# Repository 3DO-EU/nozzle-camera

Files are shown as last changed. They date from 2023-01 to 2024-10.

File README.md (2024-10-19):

# 3DO NOZZLE CAMERA

**This repository is archived. Please visit the new project at [https://github.com/3DO-EU/Enclosure-Nozzle-Camera-V2](https://github.com/3DO-EU/Enclosure-Nozzle-Camera-V2)**

3DO Discord Server

After seeing a lot of cool nozzle camera videos with hacked-up endoscopes...
We decided to make a real "Nozzle Camera" for 3D printers.
We ended up making this.
- MIPI Camera with an external USB webcam encoder (to make the camera as small as possible)
- Fixed focus lens (AF lenses start to shake and lose focus when moving fast)
- Custom FEP+Silicone USB cable, as we couldn't find any high-temperature flexible USB cables on the market.
- Custom SK6812 WWCW LED, we wanted as much light as possible while keeping the SK6812 protocol; therefore, we ended up making our LEDs similar to RGBW but with only white diodes inside.

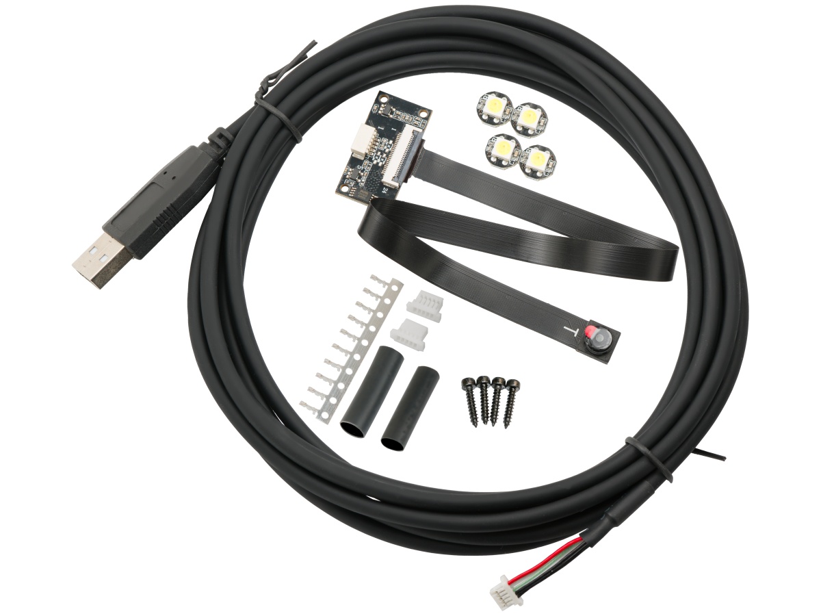
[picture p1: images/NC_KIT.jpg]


| | 4K (Sony IMX258) |
|---|---|
| Sensor Size | 1/3.06 |
| Mega-Pixel | 13MP |
| Frame Rate* | 30FPS@4K 60FPS@1080P* |
| Lens type* | Fixed Focus |
| FoV | 80Deg |
| FPC length | 25cm |
| Operating temperature** | -20°C TO 65°C |
| Storage temperature | -40°C TO 80°C |

_*These frame rates represent what the camera can achieve when directly connected, such as in OBS Studio or the Windows webcam app._

_When streaming through Crowsnest on a Raspberry Pi or a similar device, two factors limit your performance: GPU power and bandwidth._

_The new version of Crowsnest supports WebRTC/H.264 streaming, significantly reducing bandwidth requirements, making it less of a concern. However, when using the WebRTC streaming function, your GPU's encoding capabilities become the limiting factor (For Raspberry Pi 4, the GPU is limited to 1080p at 38 FPS and cannot encode 4K)._

_If you opt for the MJPEG stream in Crowsnest, no encoding is necessary, eliminating GPU limitations. However, this method requires considerably more bandwidth, so your FPS will be restricted by the available network bandwidth (using an Ethernet cable instead of Wi-Fi is recommended)._

## Video
3DO Nozzle Camera teaser (https://www.youtube.com/watch?v=BjG8rhLlGIU)

## Folders
- printers (mounts for different printers)
- hardware (CAD files to help design printer mounts)

## Pinout
PCB uses a 5P 1.0mm pitch connector.
| Pin No. | Function | Color |
|---|---|---|
| 1 | USB 5VDC | Red |
| 2 | Data - | White |
| 3 | Data + | Green |
| 4 | USB -VDC/GND| Black |
| 5 | GND/Shield  | Black (heat shrink)  |

Wire no. 5 is an optional shield/drain wire, though it will work without, we recommend installing it.

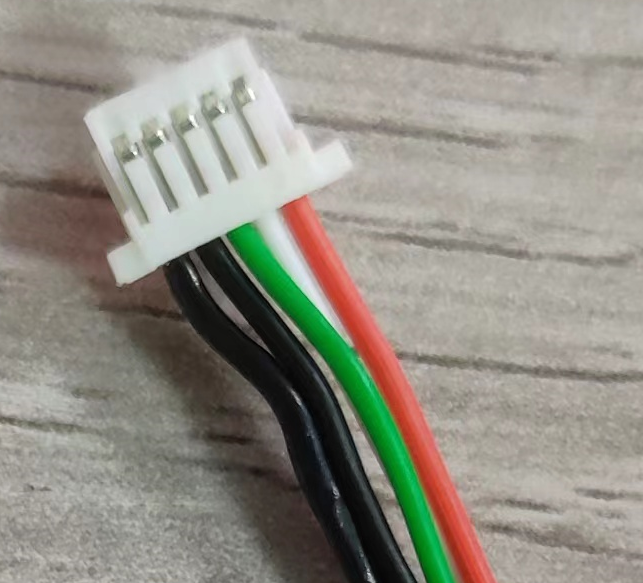
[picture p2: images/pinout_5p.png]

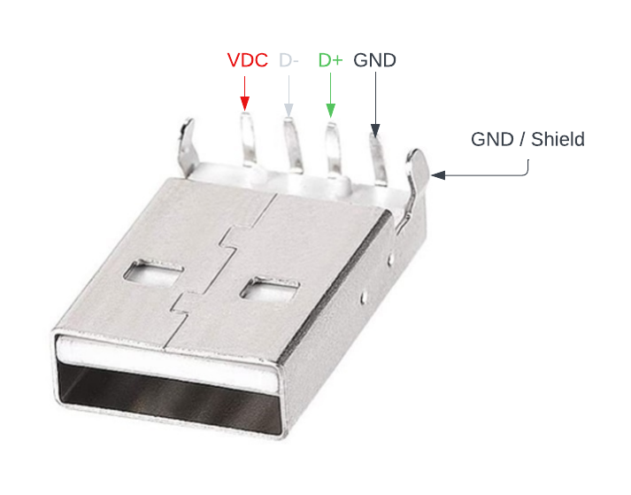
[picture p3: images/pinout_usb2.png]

</br>

## Software
The camera works as a standard UVC web camera and is, therefore, compatible with Linux, Windows, and Mac.
For streaming, we recommend using [mainsail](https://github.com/mainsail-crew/mainsail) + [crowsnest](https://github.com/mainsail-crew/crowsnest).

## FAQ
- Does it work in an enclosed printer?

Yes, though our camera is rated at 60°C, we have been running it for 48 hours in a 70°C industrial heat chamber without any issues.
- Why is FPC so long?

We decided on having 25cm between the camera and PCB for more flexibility in future mount designs.
- Can I bend/fold the FPC to make it shorter?

Yes, FPC is flexible and can be bent; if you want to fold it (180 degrees), we recommend doing this max one time in the same spot, or else you risk breaking the lanes inside FPC.

Example of folding FPC

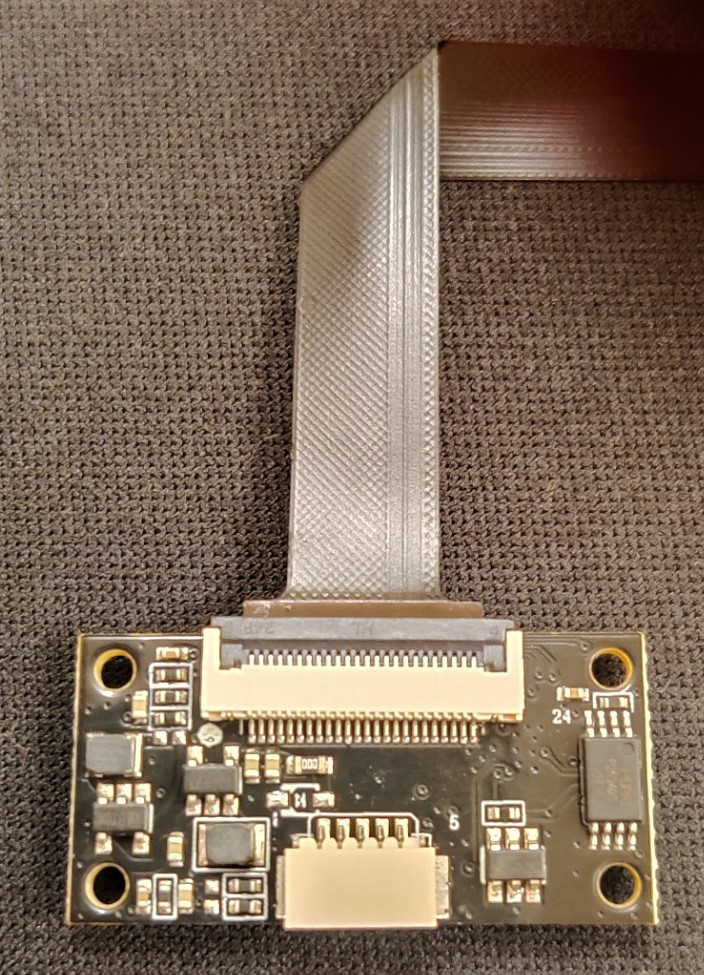
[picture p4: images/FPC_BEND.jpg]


## Contributors that made this project possible
CAD Design & Testing
- Olof Ogland (Known from Bondtech)
- Kenneth Munkholt (VZ Community)
- Dennis Jespersen (From RatRig Community)

Software Development & Testing
- Meteyou (Mainsail founder)
- KwadFan (Crowsnest founder)
- Rogerlz (Crowsnest Tester)

Beta Testers
- Mitsuma (From RatRig Community)
- Joao Barros (From RatRig Community)

## Where to buy
EU / UK



USA





<p xmlns:cc="http://creativecommons.org/ns#" >This work is licensed under <a href="https://creativecommons.org/licenses/by-nc-sa/4.0/?ref=chooser-v1" target="_blank" rel="license noopener noreferrer" style="display:inline-block;">CC BY-NC-SA 4.0</a></p>

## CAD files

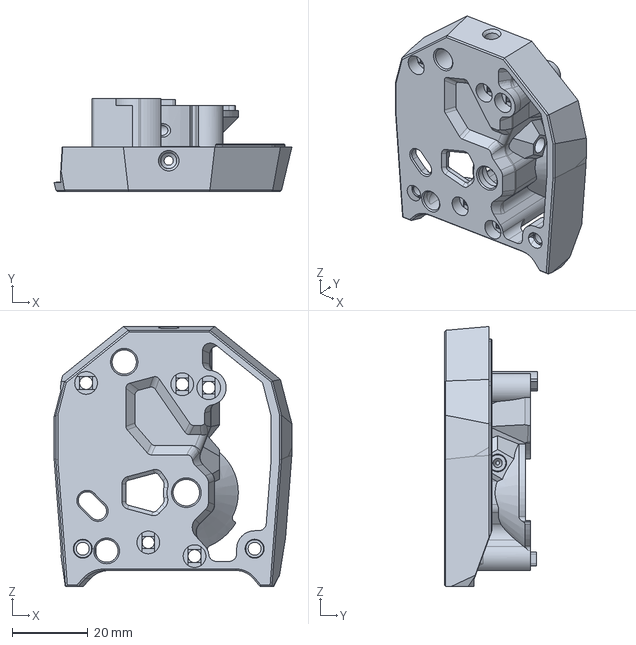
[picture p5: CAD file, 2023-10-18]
printers/Voron_Stealthburner/CAD/Misc/CW2 main body 3DO mod_updated.step
62.8 x 24.7 x 68.7 mm

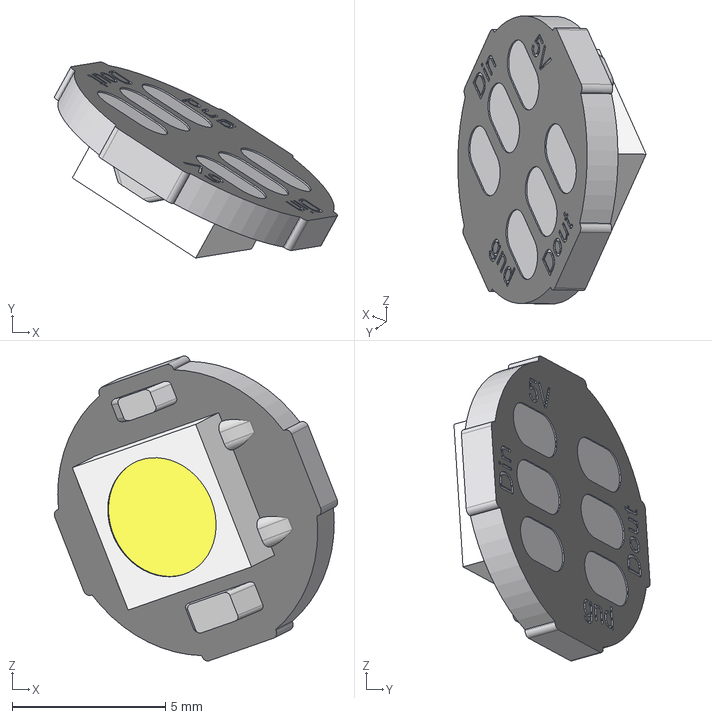
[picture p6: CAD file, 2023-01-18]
hardware/3NC_LED.stp
9.24 x 6.39 x 9.95 mm

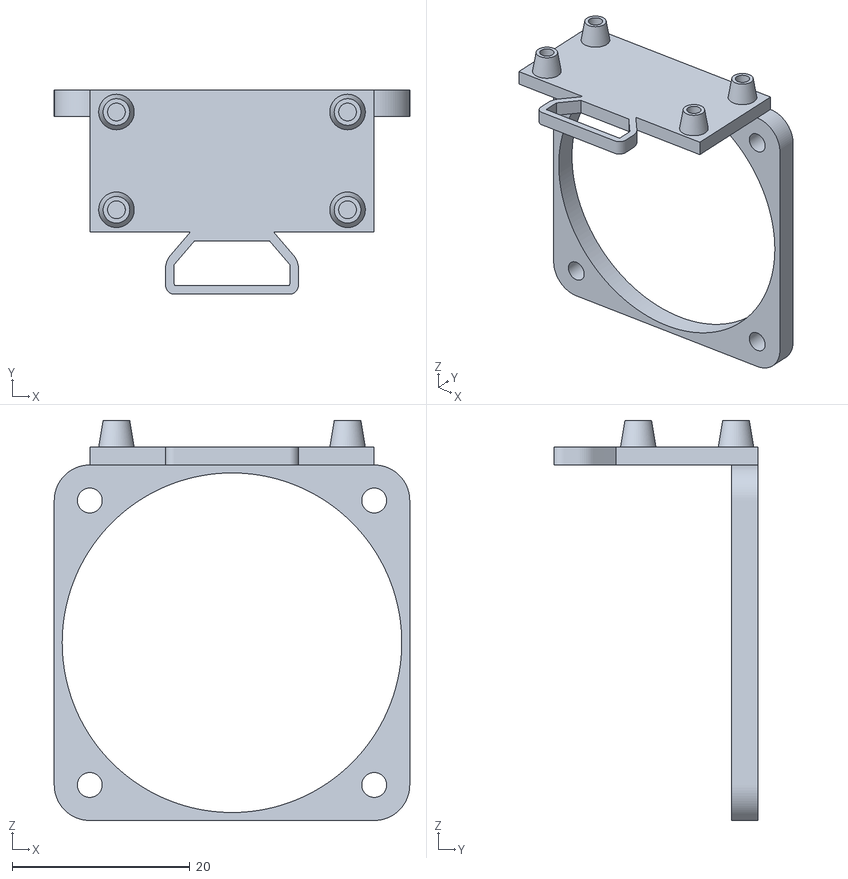
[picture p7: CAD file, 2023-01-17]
printers/EVA_2_4/Body1.stl
40.0 x 23.0 x 45.0

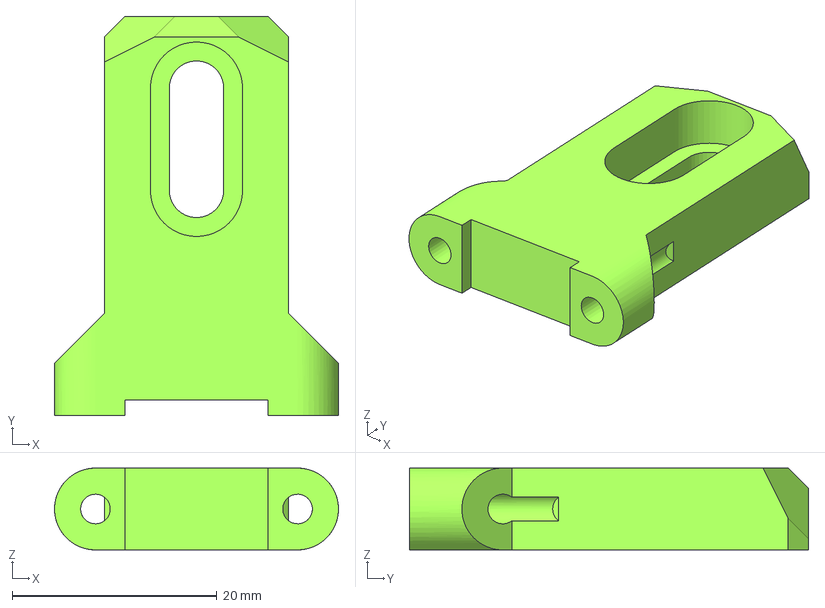
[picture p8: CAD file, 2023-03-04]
printers/EVA_3/Y end stop extended 15mm.3mf
27.7 x 39.0 x 8.00 mm

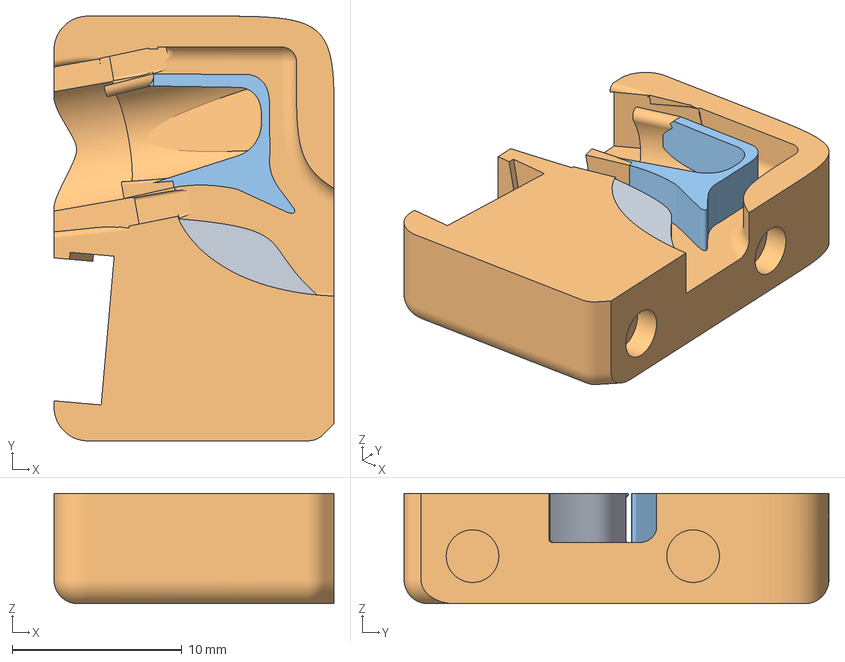
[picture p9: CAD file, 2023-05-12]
printers/Prusa I3 MK3/Nozzle-Cam 3DO 4K V13 LED Pearl A.3mf
16.5 x 25.0 x 6.50 mm
K_rper_15
Cambody
K_rper_16

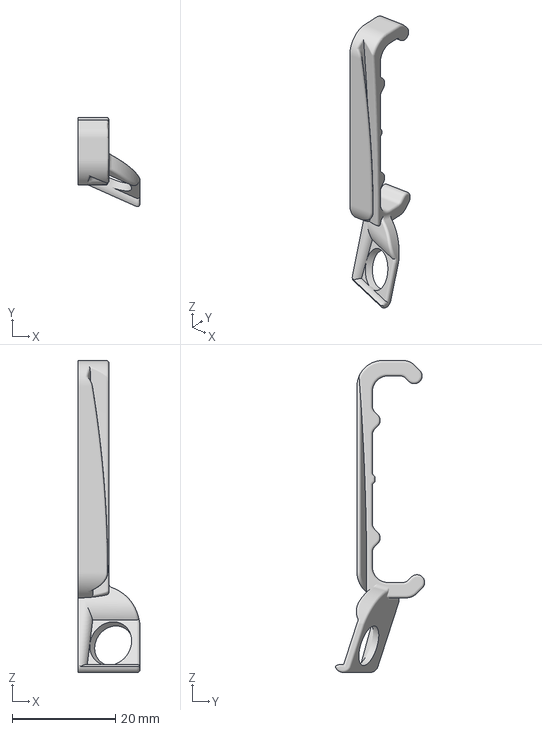
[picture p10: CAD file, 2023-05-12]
printers/Prusa Mini/3DO Nozzle Cam Fan Mount for Prusa Mini - 22 deg right and 16.5 deg down V7.3.3mf
12.0 x 17.3 x 60.4 mm

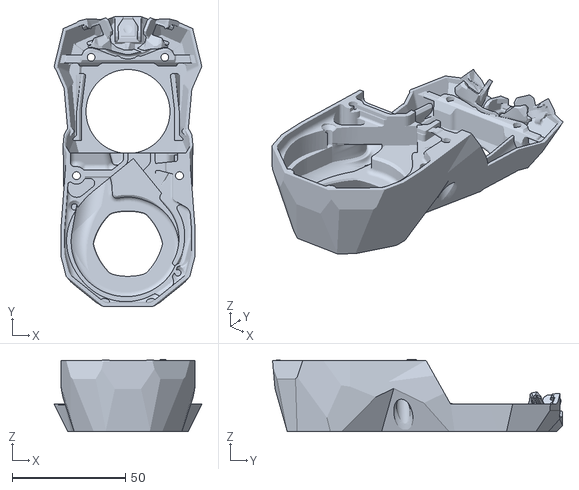
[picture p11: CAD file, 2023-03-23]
printers/Voron_Stealthburner/STLs/Standard/Cam_mount_SB_HEX.stl
65.1 x 127.8 x 31.8

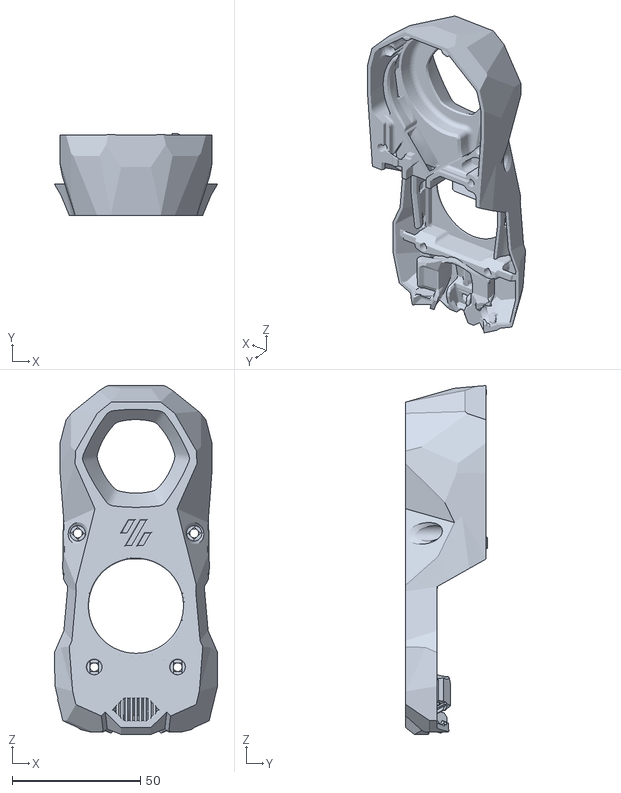
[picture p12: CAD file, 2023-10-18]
printers/Voron_Stealthburner/STLs/UHF/Cam_mount_SB-UHF_Grille_eyebrows.stl
63.6 x 31.8 x 136.1

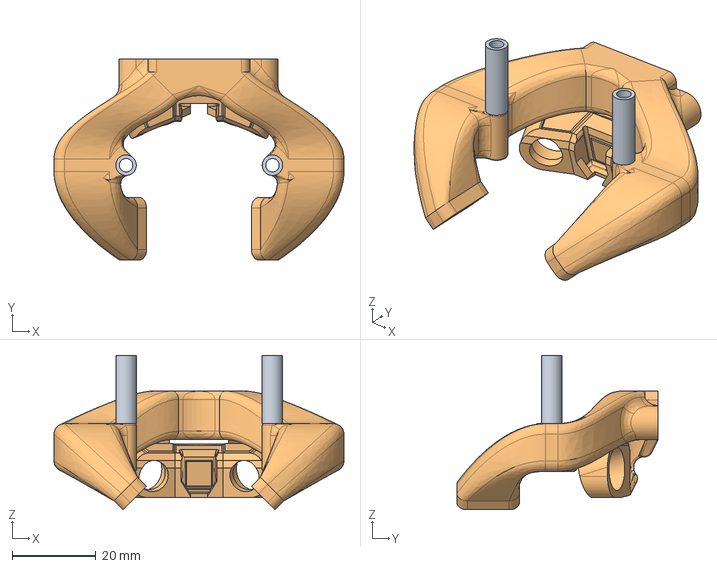
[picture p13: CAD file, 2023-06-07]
printers/VzBoT/Duct.step
69.3 x 48.2 x 36.9 mm

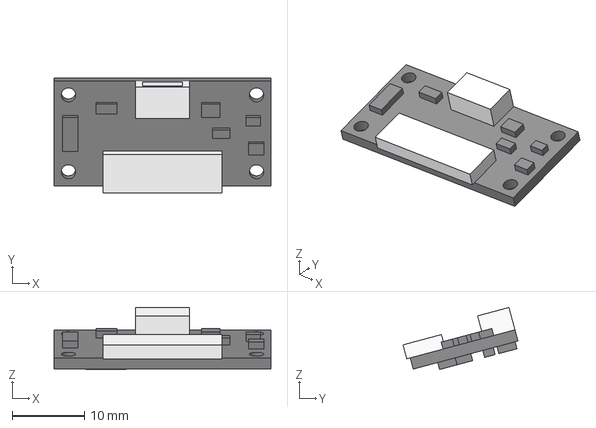
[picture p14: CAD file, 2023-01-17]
hardware/3NC_pcb.stp
30.0 x 15.9 x 8.58 mm

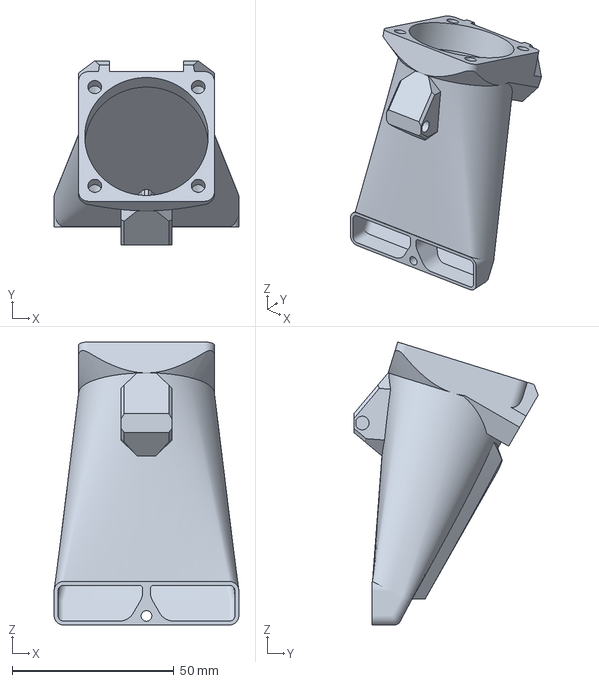
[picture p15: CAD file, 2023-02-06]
printers/EVA_3/3DO EVA 4028 fan inlet nozzle cam pcb mount V2.3mf
57.2 x 57.1 x 87.6 mm

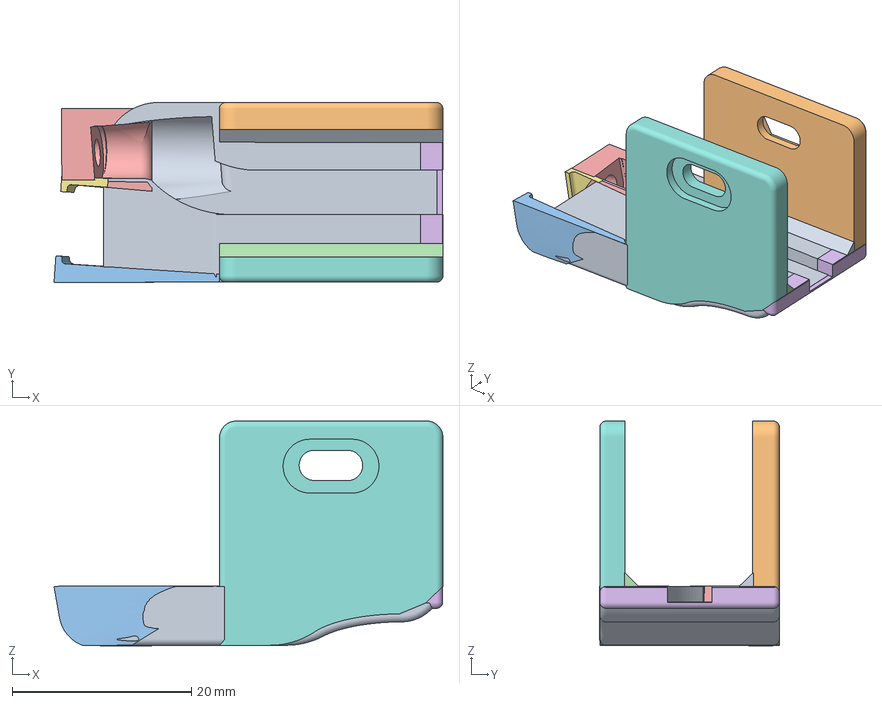
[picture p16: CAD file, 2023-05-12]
printers/Prusa I3 MK3/Nozzle-Cam 3DO 4K V11.3mf
43.4 x 20.1 x 25.1 mm
Basis
Klammer_Links_(2)
Kamera__(2)
Winkel
K_rper_17
K_rper_13
Kamera_
Klammer_Links_(1)
Winkel_(2)

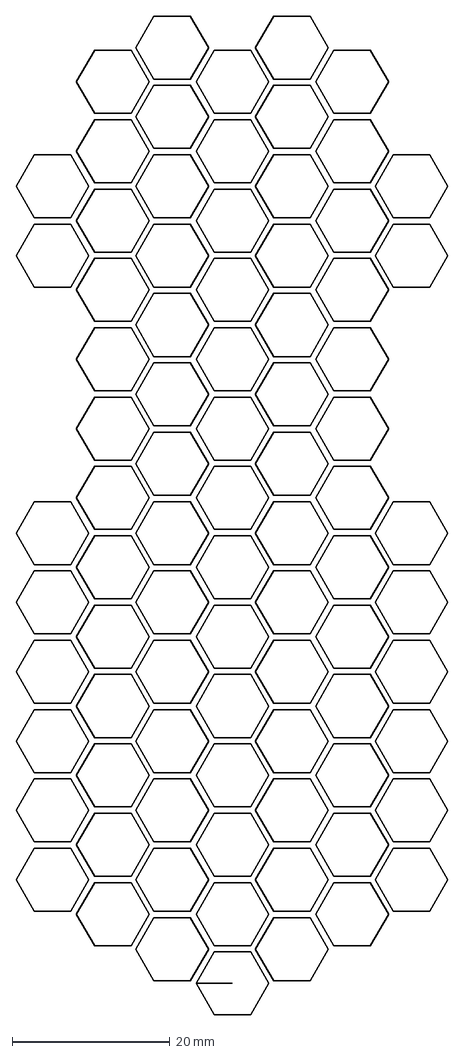
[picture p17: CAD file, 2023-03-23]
printers/Voron_Stealthburner/CAD/Misc/hex_pattern.dxf
54.8 x 126.7 mm

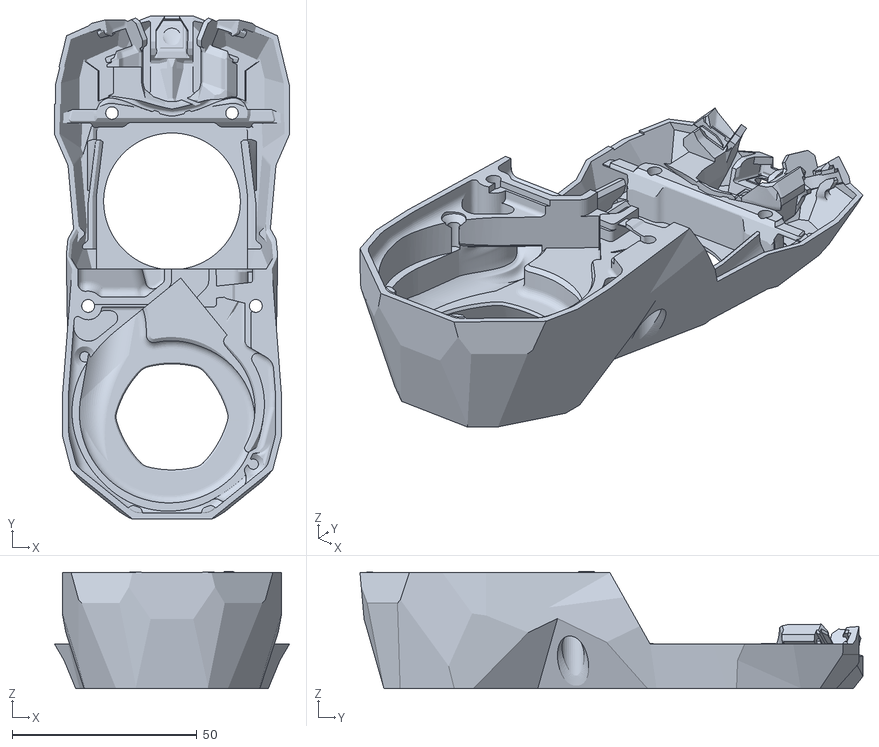
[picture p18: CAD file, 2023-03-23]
printers/Voron_Stealthburner/STLs/UHF/Cam_mount_SB-UHF_HEX.stl
63.6 x 136.1 x 31.8

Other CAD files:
printers/Voron_Stealthburner/STLs/Misc/CW2_main_body_3do_pcb_cutout_updated.stl
printers/Voron_Stealthburner/STLs/Misc/CW2_main_body_3do_pcb_cutout.stl
printers/Voron_Stealthburner/CAD/Misc/CW2 main body 3DO mod.step
printers/Voron_Stealthburner/STLs/Standard/Cam_mount_SB-V_stroke.stl
hardware/3NC_PCB_DRAWING.dwg
hardware/3NC_mount_geometry_V2.step
printers/EVA_3/3DO EVA vulcano duct nozzle cam V2.3mf
printers/EVA_3/3DO nozzle cam back cover.3mf
printers/EVA_3/3DO nozzle cam pcb cover V2.3mf
printers/Prusa I3 MK3/Nozzle Cam 3DO Komplett V11 PRINT.3mf
printers/Prusa I3 MK3/Nozzle Cam 3DO PCB Case V9.3mf
printers/Prusa I3 MK3/Nozzle Cam 3DO PCB Case V9.stl
printers/Prusa I3 MK3/Nozzle Cam 3DO PCB Top V9.3mf
printers/Prusa I3 MK3/Nozzle Cam 3DO PCB Top V9.stl
printers/Prusa I3 MK3/Nozzle-Cam 3DO 4K BoxHolder V9.3mf
printers/Prusa I3 MK3/Nozzle-Cam 3DO 4K BoxHolder V9.stl
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

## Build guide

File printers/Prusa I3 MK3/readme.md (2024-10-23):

You will find detailed Assembly instructions on the printable website:
https://www.printables.com/de/model/433376-3do-nozzle-cam-mount-for-prusa-i3-mk3-improved-ver

And for the older version here:
https://www.printables.com/de/model/427054-3do-nozzle-camera-mount-for-prusa-i3-mk3s

These are the improvements:
Now with better light (3W pearl LED) and improved camera angle. New camera housing

I recently upgraded my former model (https://www.printables.com/de/model/427054-3do-nozzle-camera-mount-for-prusa-i3-mk3s) of the gorgeous 3DO HiRes Nozzlecam with Sony video chip (https://3do.dk/3do-camera/2681-1913-3do-nozzle-camera-kit-v2-sony-4k-for-3d-printers.html).

These are the improvements:
• Changed camera angle to center nozzle in picture
• Better lighting with brighter 3W pearl 4000K LED
• Body now made of two parts with pass marks for easier printing

Only the camera mount is changed over the previous model. PCB box, box mount and lid are the same and have not been touched. For assembly and general information see the original design.
The LED is a 3,7 Volt pearl cob led (like this one). You should choose the ‘natural white’ variant with 4000K because it gives the best natural light. With 5V power supply (taken from Einsy Rambo board) you need a 80-90 Ohm pre-resistor to drive the LED. The resistor is soldered directly to the + contact of the LED and isolated with shrink tube.
The Camera housing now is made of two parts (Part A and part B) that snap together with two pass marks. Print quality is better and stronger this way. Still no supports needed. I put them together with a drop of superglue.

After assembling camera mount and PCB Case and securing all cables you can adjust the focus of the cam by loosening the screw next to the cam and pushing the mount a bit for- or backwards So that the focus sits excactly in the tip of the nozzle.
Someone asked me: “why not build it with two leds?“ That’s because the mount must not be too wide or it will interfere with the frame of the Prusa i3. There is just not enough room for two LEDs when mounting the camera this way.
Printed in Prusament PETG (no supports needed).
The assembly is a bit tricky so please refer to my instructions and be extremely careful when handling the camera or the PCB.
 
 I now am completely content with the design and enjoy the macro-pictures of the nozzle while printing. It was quite a long developing process and a had to pay for some of my mistakes in the beginning (breaking more than one 3DO cameras ... had to buy new ones). At 3DO they must be wondering what I am doing with all those cameras :-)
Update (Comment):

@SpartanFPV_40710 reminded me, that it is not the stock x-axis cable support, that my camera holder is mounted on. I almost forgot I upgraded this part. So before adding my camera mount upgrade the x-axis cable support with this model: https://www.printables.com/de/model/139656- prusa-i3-mk3-x-axis-cable-holder-roomy-revo-editio . That is the one I have installed a long time ago and it is a great improvement anyway.

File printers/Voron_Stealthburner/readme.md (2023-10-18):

# Files for common hotends
[Standard models](./STLs/Standard/)

# Files for extended hotends (Rapido UHF / Mosquito Magnum Plus /..)
[UHF models](./STLs/UHF/)

# Other files like PCB mounts etc.
[Misc models](./STLs/Misc/)

# Pictures
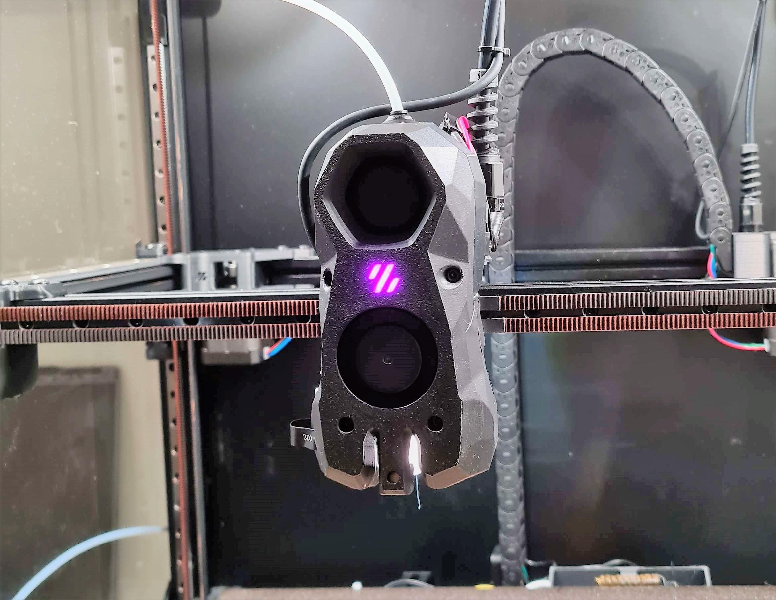
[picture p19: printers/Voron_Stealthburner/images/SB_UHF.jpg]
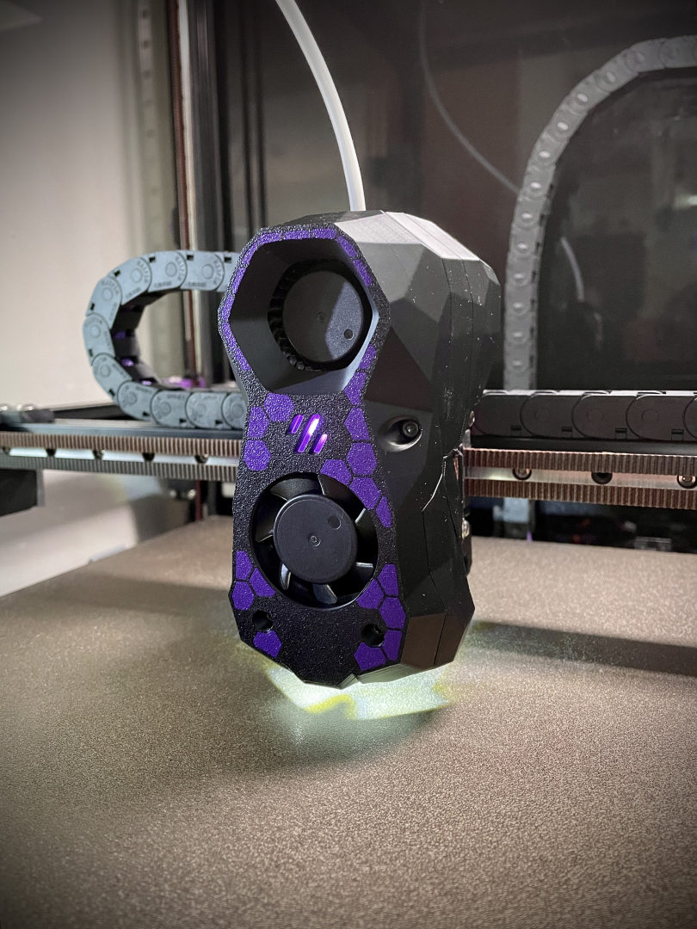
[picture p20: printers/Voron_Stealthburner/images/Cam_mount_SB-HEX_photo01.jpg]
  
More pictures can be found in the [Showroom](./images/Showroom/showroom.md)

# FPC Routing internal
Camera PCB can be mounted in front of the extruder using VHB tape. (Only tested with LGX Lite extruder)

It's easiest if you route FPC before led/fan wires.

- Option 1 - To the left  
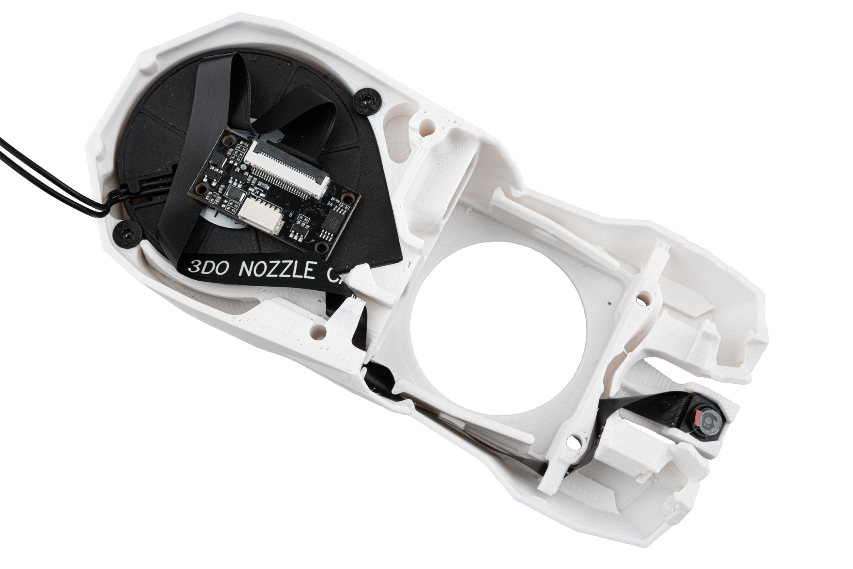
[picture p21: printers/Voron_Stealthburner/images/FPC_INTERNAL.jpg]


- Option 2 - To the right  
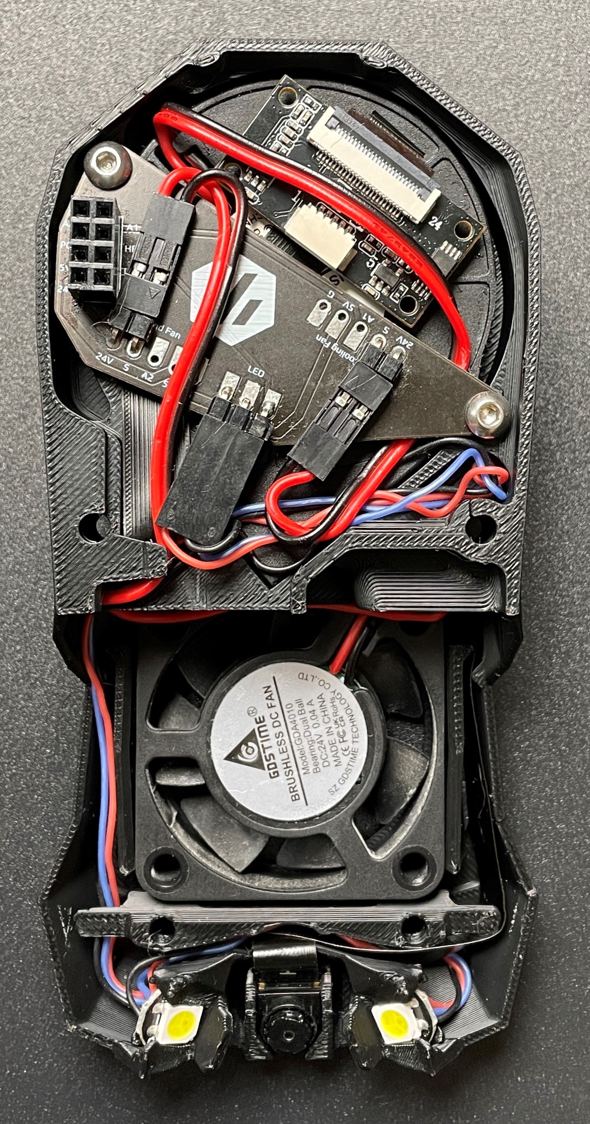
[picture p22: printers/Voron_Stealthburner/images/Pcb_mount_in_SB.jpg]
  
More images <a href="./images/FPC-routing/fpcrouting.md">here</a>

### CW2 main body with cutout
To make some extra room for the usb cable when using the 2-piece hartk PCB you can use this modified model with a cutout for it. The model with "_updated" in the name was updated for the July 11th 2023 update of the CW2. 

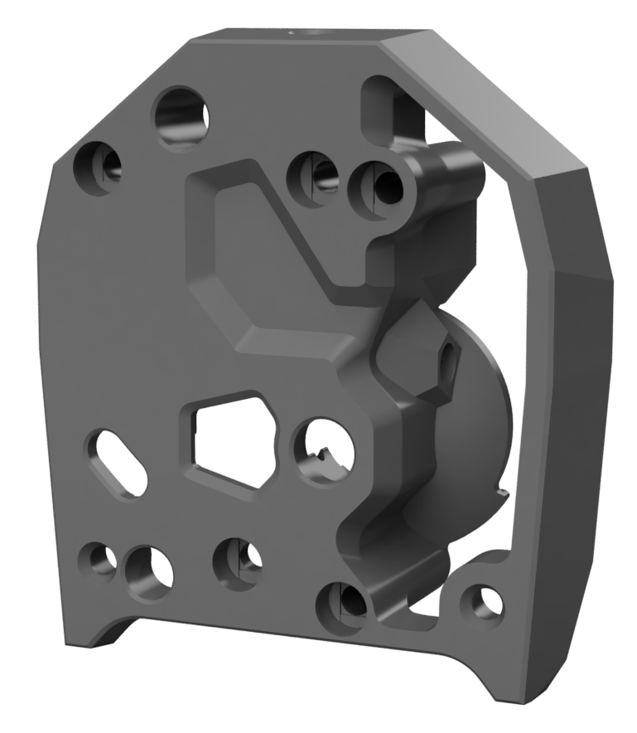
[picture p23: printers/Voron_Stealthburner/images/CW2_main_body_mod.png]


## WARNING
Do not pull to hard on the FPC, you may risk to rupture it.

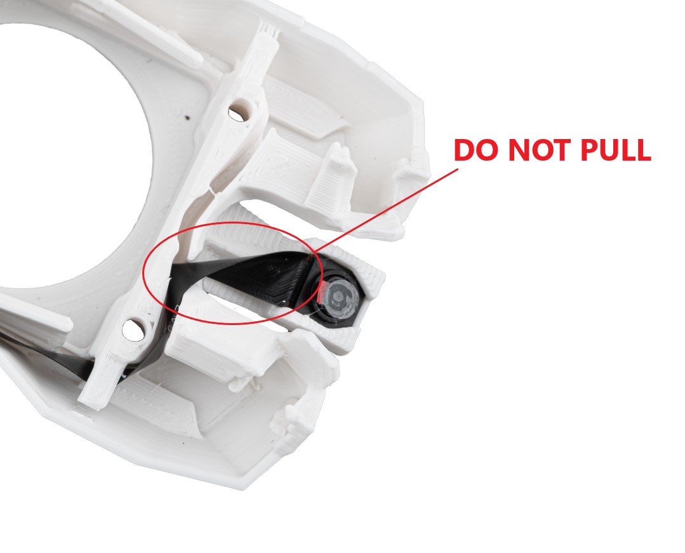
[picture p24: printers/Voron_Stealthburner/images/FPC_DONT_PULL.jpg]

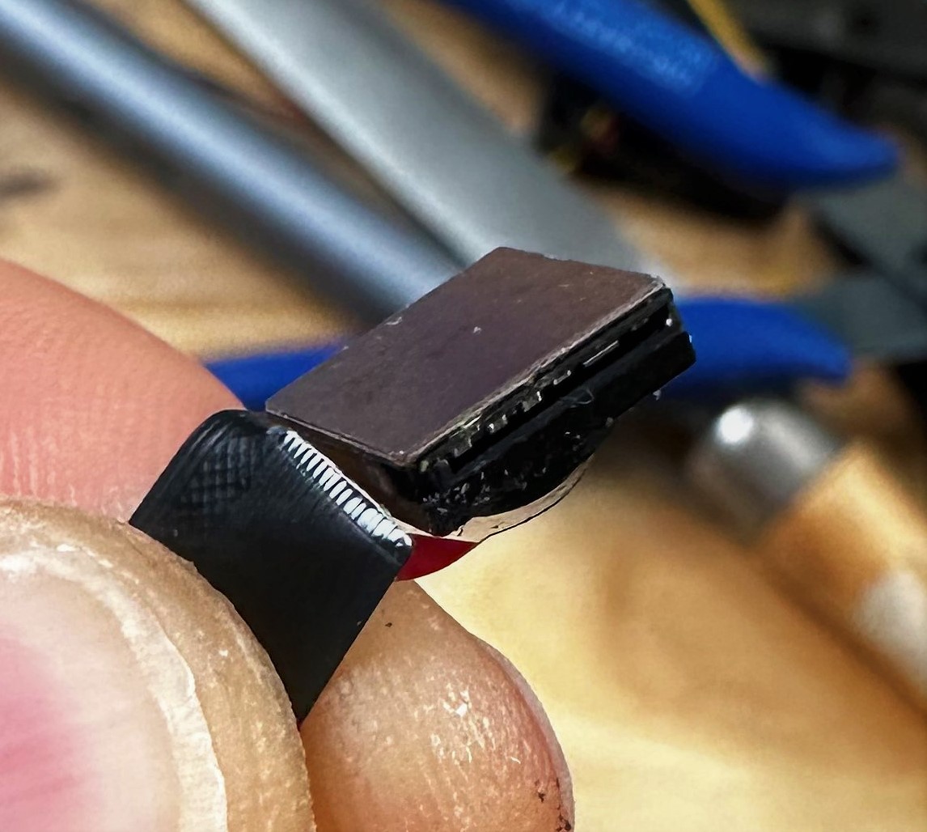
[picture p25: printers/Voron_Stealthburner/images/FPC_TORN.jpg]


# FPC Routing external
Camera PCB can be mounted using the Stealth burner adxl mount (PCB_mount_SB.stl)

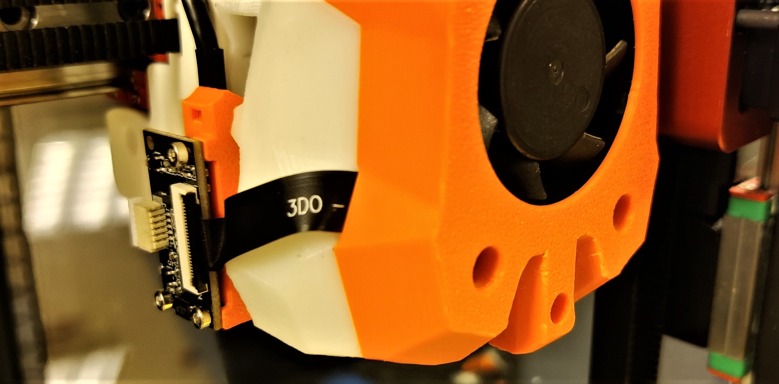
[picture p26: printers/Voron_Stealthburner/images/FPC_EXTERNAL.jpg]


# Printing instructions
 - Use normal Voron printing guidelines
    - Material: ABS
    - Layer height: 0.2mm
    - Extrusion width: 0.4mm
    - Infill type: Grid, Gyriod, Honeycomb, Triangle or Cube
    - Infill percentage: 40%
    - Wall count: 4
    - Solid top/bottom layers: 5

# Software
If you are using the standard Voron configuration with Klipper/Mainsail/Crowsnest the software configuration to add a new camera is fairly straightforward. On a Raspberry Pi4 at 800x600 resolution 30-60FPS is achievable. The focal plane is quite small so a large output resolution is not necessary.
1. Install and plug-in the 3DO nozzle camera
2. Restart the printer
3. Navigate to and view crowsnest.log to determine the video device of the new nozzle camera (~/printer_data/logs/crowsnest.log). The entry you're looking for looks something like this:
```
[03/21/23 14:14:34] crowsnest: /dev/v4l/by-id/usb-XCG-221208-J_3DO_NOZZLE_CAMERA_4K_01.00.00-video-index0 -> /dev/video2
```

4. Udate crowsnest.conf with the new device
```
[cam 2]
mode: mjpg                              # mjpg/rtsp
port: 8081                              # Port 8081 equals /webcam2/?action=[stream/snapshot]
device: /dev/video2                     # See Log for available ...
resolution: 800x600                     # widthxheight format - on a raspberry pi 4 30-60 FPS is acheivable with 800x600
max_fps: 60                             # If Hardware Supports this it will be forced, ohterwise ignored/coerced.
#custom_flags:                          # You can run the Stream Services with custom flags.
#v4l2ctl:                               # Add v4l2-ctl parameters to setup your camera, see Log what your cam is capable of.
```
5. Add your new webcam to the Mainsail UI using the endpoint for the port you selected: `/webcam2/?action=[stream/snapshot]`

If necessary, more details about configuing crowsnest can be found here: https://github.com/mainsail-crew/crowsnest

# Credits
Initial design by Olof Ogland  
Mods by Panzarkatten

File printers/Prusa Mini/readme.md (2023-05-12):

https://www.printables.com/model/433537-3do-nozzle-cam-fan-mount-for-prusa-mini

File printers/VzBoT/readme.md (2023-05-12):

# Files needed
## For standard 5015 part cooling:
-	1 x Camduct.stl
-	2 x spacer.stl
-	1 x upper_duct.stl
-	1 x PCB_cover.stl
## For CPAP part cooling:
-	1 x Camduct.stl
-	2 x Spacer.stl
-	1 x CPAP_upper_duct.stl
-	1 x PCB_cover.stl

# Installation of the camera
Start by getting the FPC approximately halfway through the slot in the camduct. Then proceed to push the cam in place – it takes a bit of force so be carefull. Afterwards pull the FPC all the way through the slot. Make sure not to pull too hard.
<br><br>
Next up you need to pull the FPC through the slot in the CPAP upper duct. Make sure it is oriented correctly. Now connect the PCB tho the FPC.
<br><br>
Now fold up the FPC so that you end up with something like this and use the four M2x10 screws to screw on both the PCB cover and PCB. Again make sure to use caution or else you might damage the FPC.
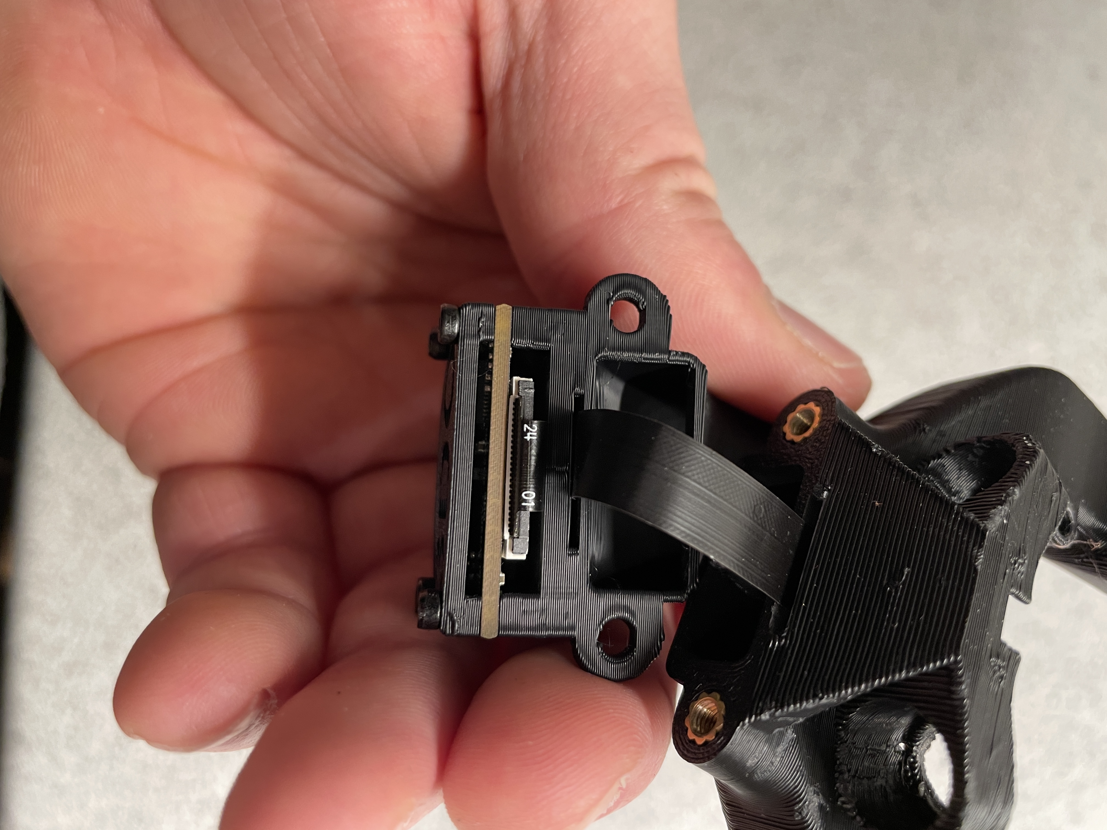
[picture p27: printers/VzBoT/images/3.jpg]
<br><br>
Next step is to wire up the LED’s and push them in the LED holders. They are friction fit so they won’t fall out even at high speeds and accelerations. Then you have to mount the sub assembly to the VzPrinthead like you normally would. It can be a bit cumbersome trying to align all three parts. But you’ll soon be done. You should end up with something like this.
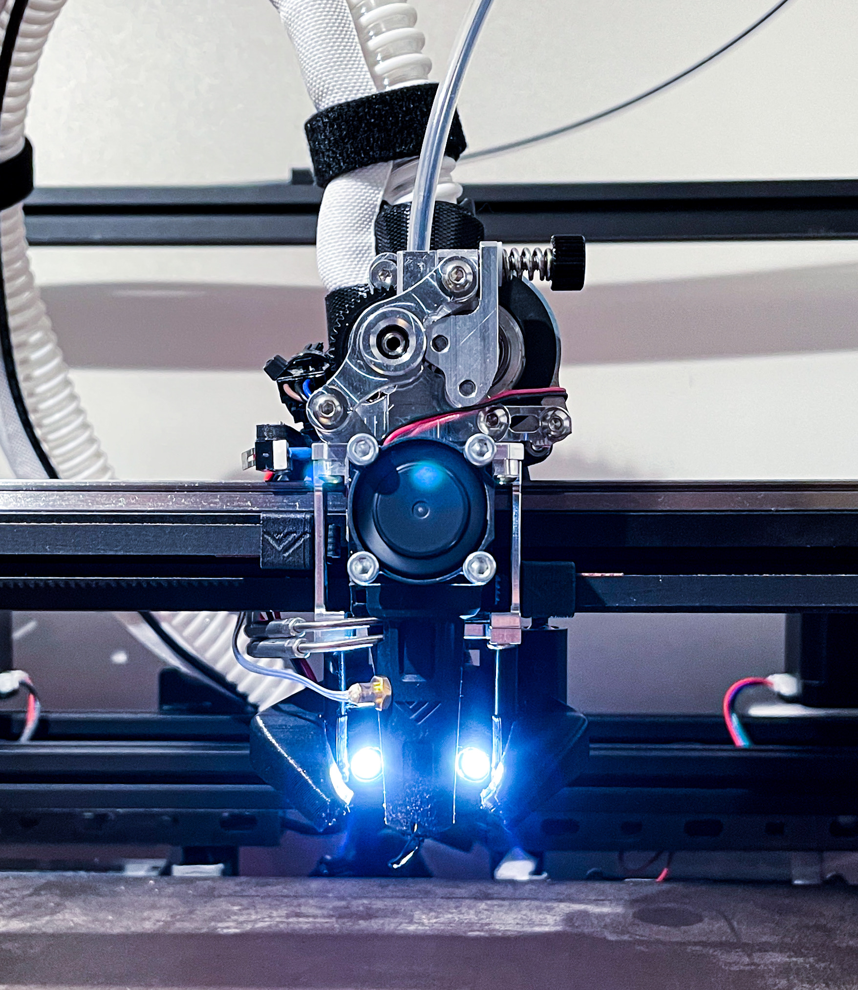
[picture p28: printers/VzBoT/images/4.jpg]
<br><br>
# Credits
Design by Kenneth Munkholt Sørensen

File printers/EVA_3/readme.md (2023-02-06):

# BOM
- 11 pcs heat inserts for all the parts 
- 2 pcs M3x10 (for the bottom cover)
- 2 pcs M3x10 (for the mount of the fan inlet to EVA back)
- 2 pcs M3x(8 or 10) (for the pcb cover)
- the rest is from standard EVA setup

**FYI this is only for the volcano style setup and 4028 fan**

# Credits
Design by Dennis Jespersen (Dj_Designs)

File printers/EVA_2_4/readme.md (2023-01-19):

# BOM

- 4pcs 2x10mm SHCS Self tapping screws
- 2pcs M3x30
- 2pcs x M3x35

# Pictures
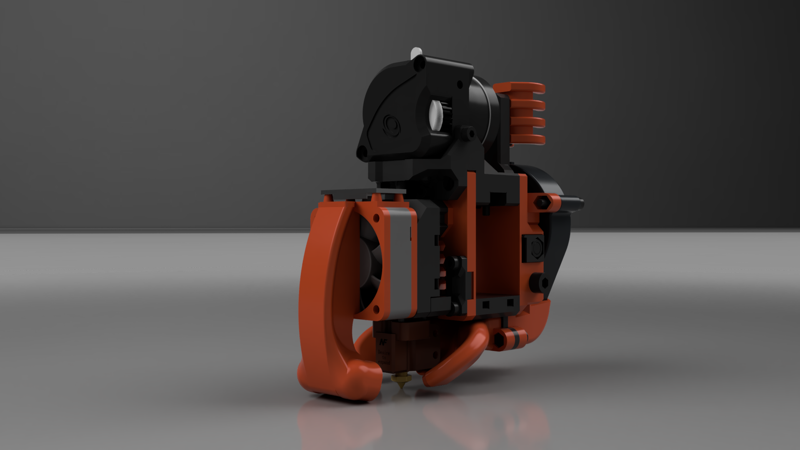
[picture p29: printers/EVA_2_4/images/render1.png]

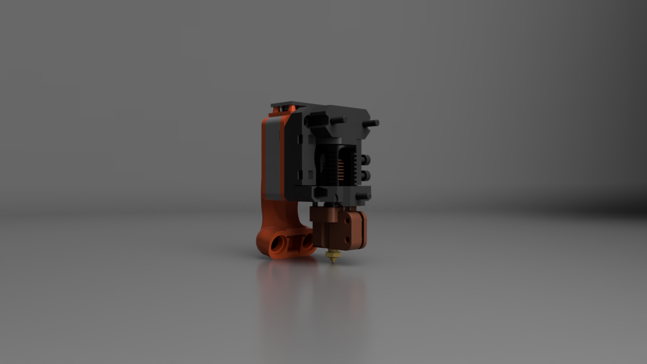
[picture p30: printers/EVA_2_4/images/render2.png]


# Credits
Design by Kenneth Munkholt

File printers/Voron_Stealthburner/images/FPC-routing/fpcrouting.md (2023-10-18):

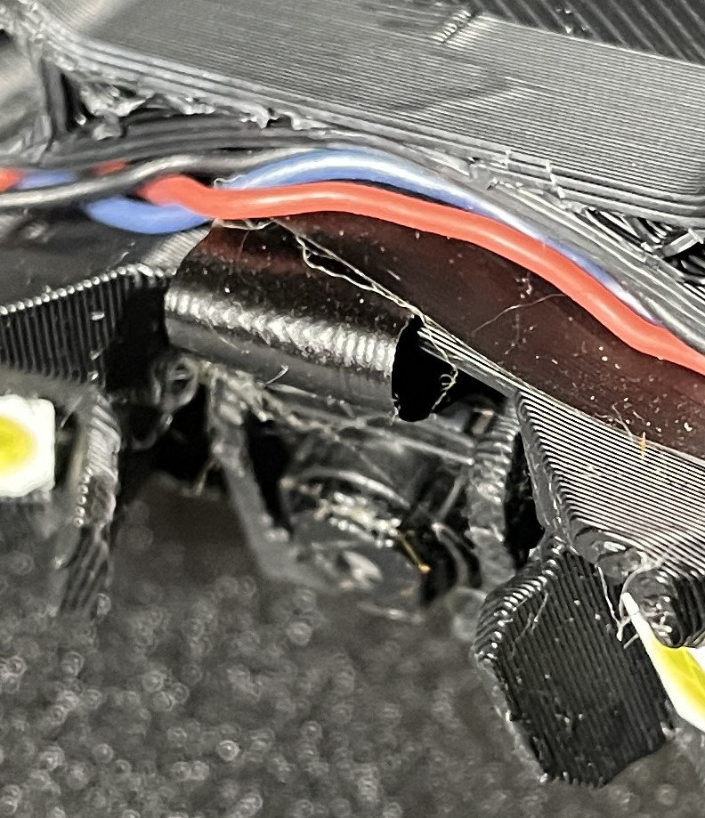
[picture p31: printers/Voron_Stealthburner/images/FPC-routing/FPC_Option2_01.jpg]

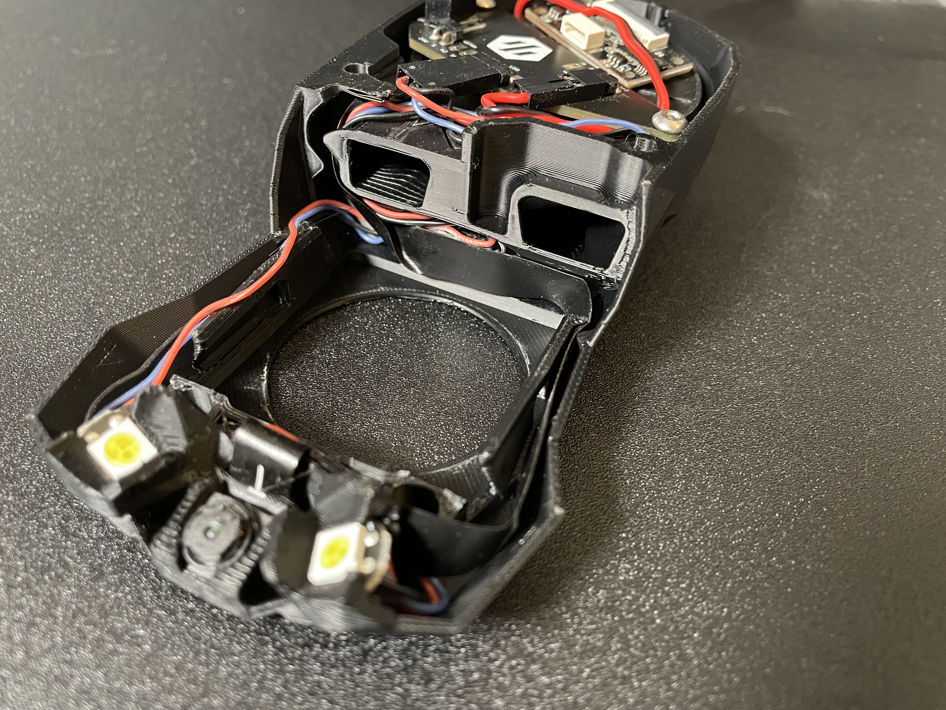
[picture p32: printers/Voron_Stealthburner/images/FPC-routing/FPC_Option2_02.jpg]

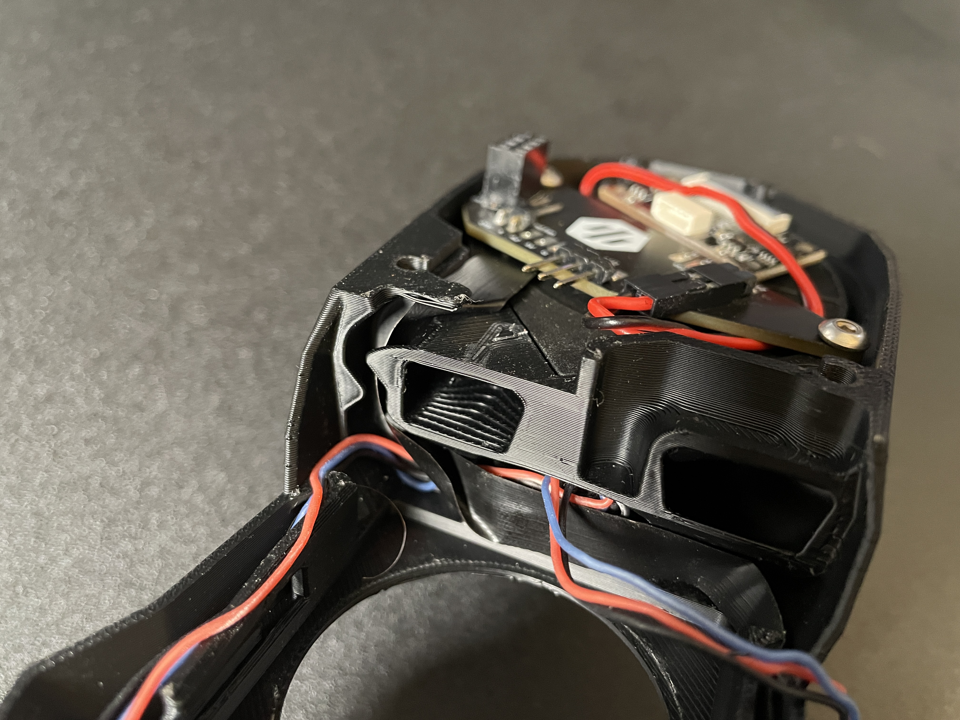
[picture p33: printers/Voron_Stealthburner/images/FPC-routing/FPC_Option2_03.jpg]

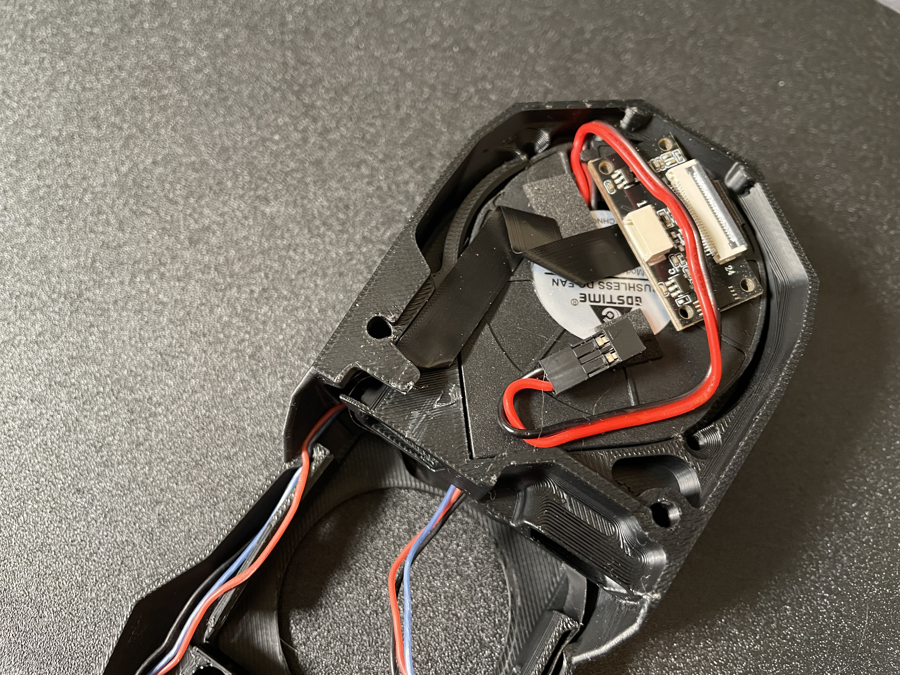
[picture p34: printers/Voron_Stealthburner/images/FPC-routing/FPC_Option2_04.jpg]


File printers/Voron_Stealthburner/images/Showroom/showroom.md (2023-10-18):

## V-Edition
------
### With one color
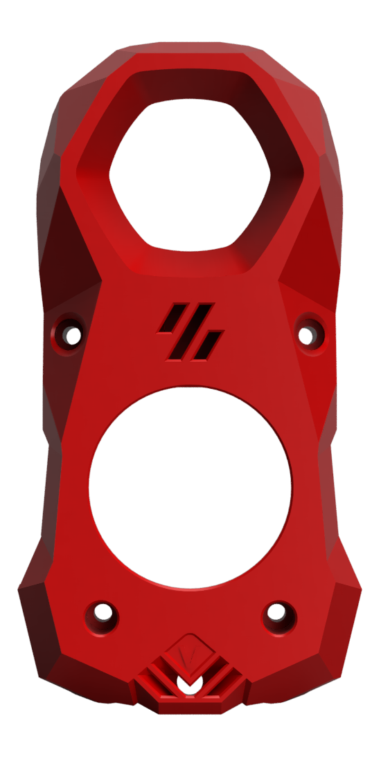
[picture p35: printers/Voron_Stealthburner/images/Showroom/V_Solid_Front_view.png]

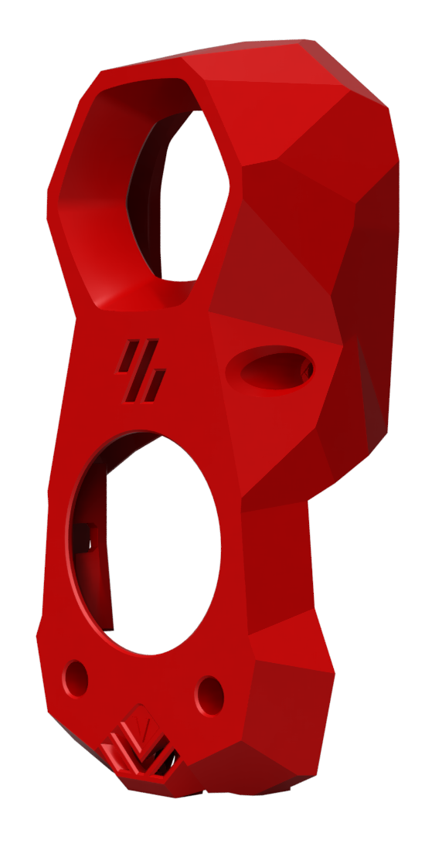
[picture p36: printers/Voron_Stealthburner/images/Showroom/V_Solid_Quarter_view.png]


### With color change
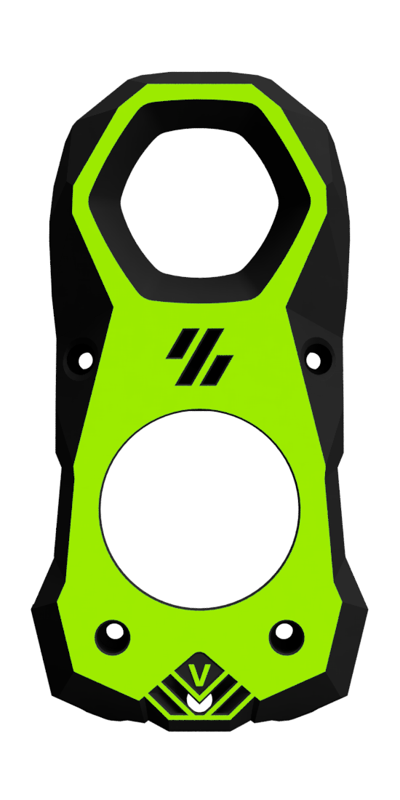
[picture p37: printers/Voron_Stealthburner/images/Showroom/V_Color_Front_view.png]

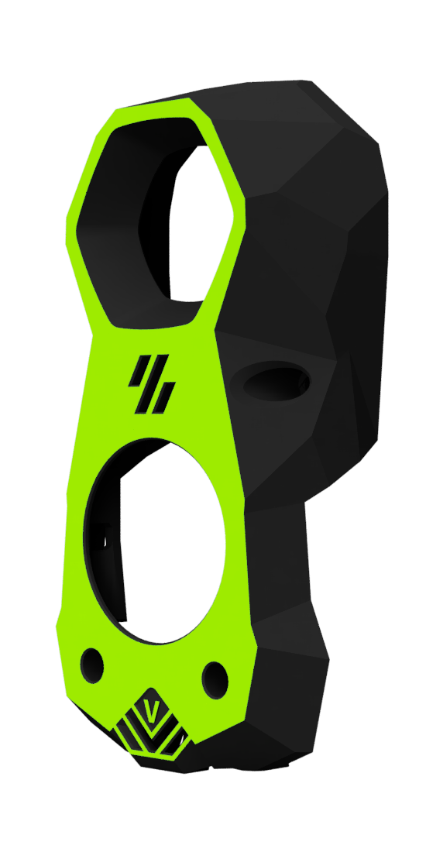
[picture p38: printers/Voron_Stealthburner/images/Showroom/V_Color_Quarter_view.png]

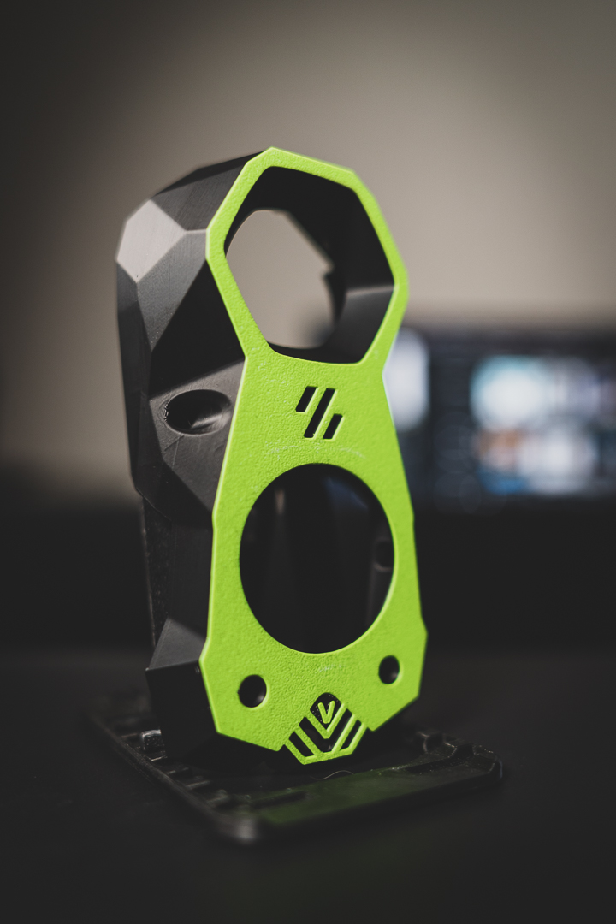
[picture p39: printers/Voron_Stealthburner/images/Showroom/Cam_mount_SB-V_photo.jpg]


### With stroke
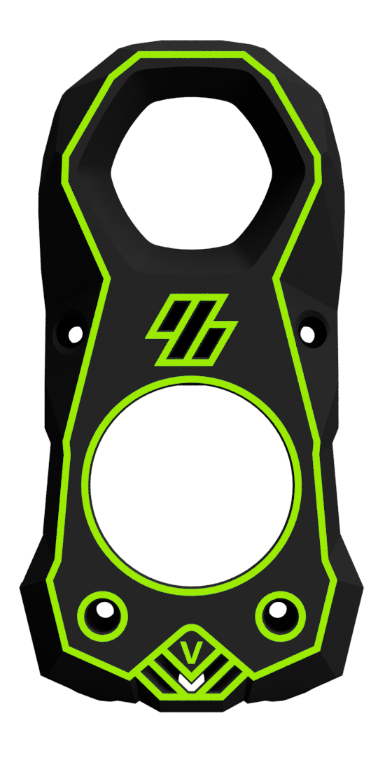
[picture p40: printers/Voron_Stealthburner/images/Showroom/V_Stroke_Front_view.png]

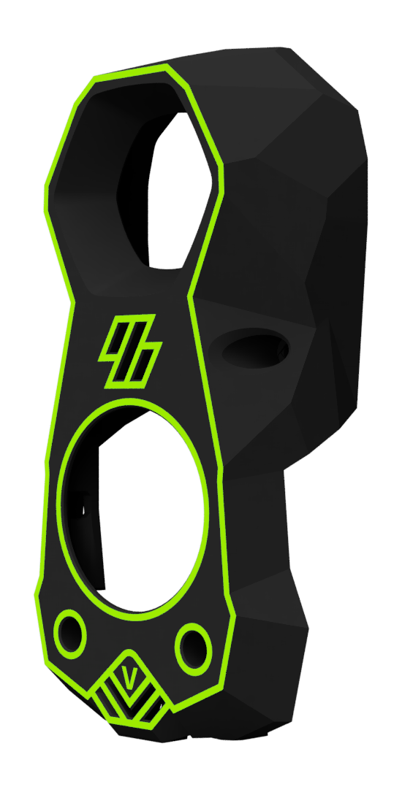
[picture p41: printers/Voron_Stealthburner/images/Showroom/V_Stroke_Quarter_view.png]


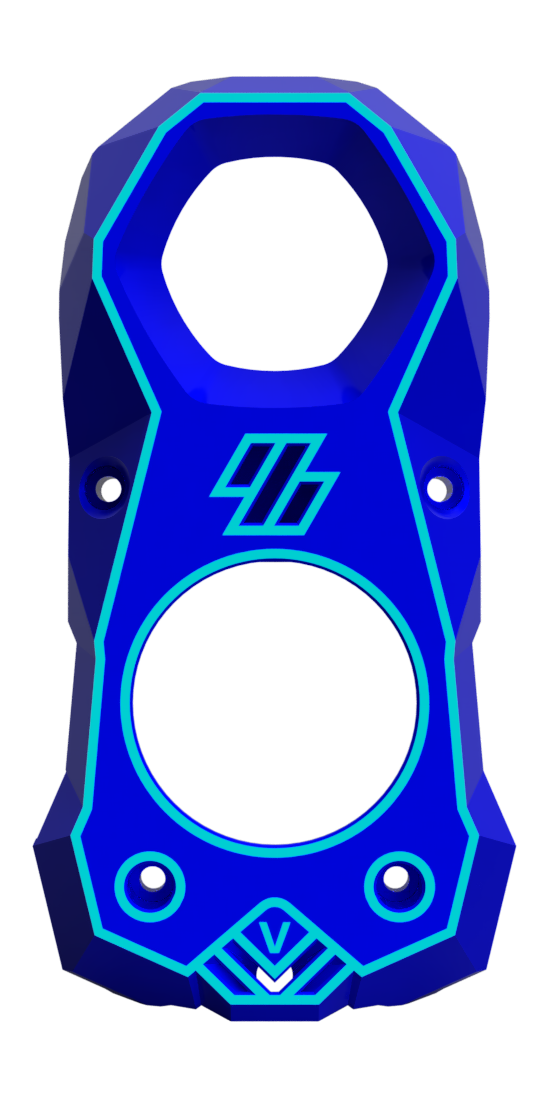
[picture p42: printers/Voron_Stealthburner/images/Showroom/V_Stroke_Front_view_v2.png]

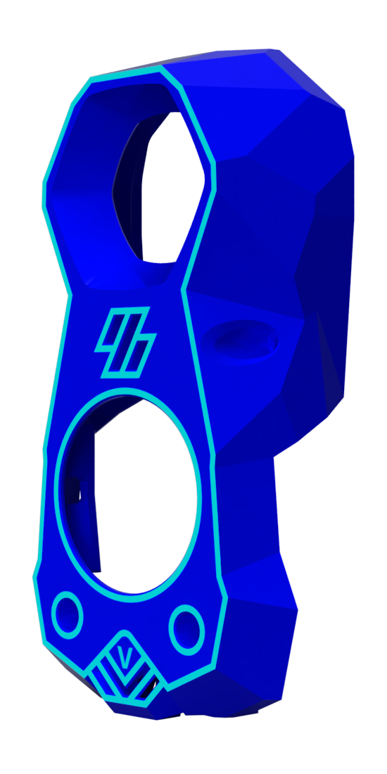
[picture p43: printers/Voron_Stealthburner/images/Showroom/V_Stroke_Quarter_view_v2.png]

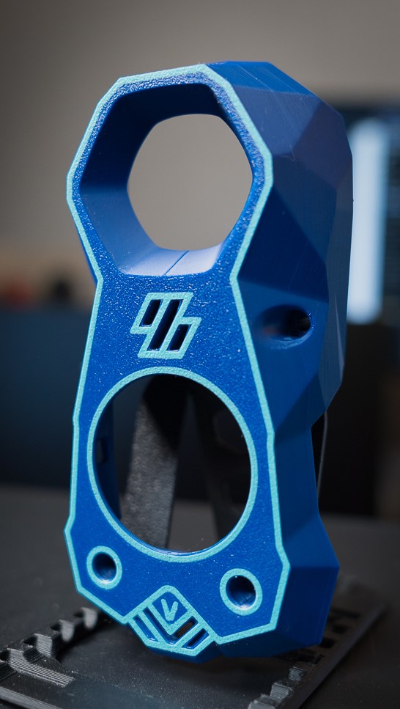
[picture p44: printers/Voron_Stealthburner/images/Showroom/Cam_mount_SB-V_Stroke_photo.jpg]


*Note that V-Stroke is a separate file*

## Grille Edition
------
Similar to the V-Edition but with a grille pattern which also lets air in to the camera.

### With one color
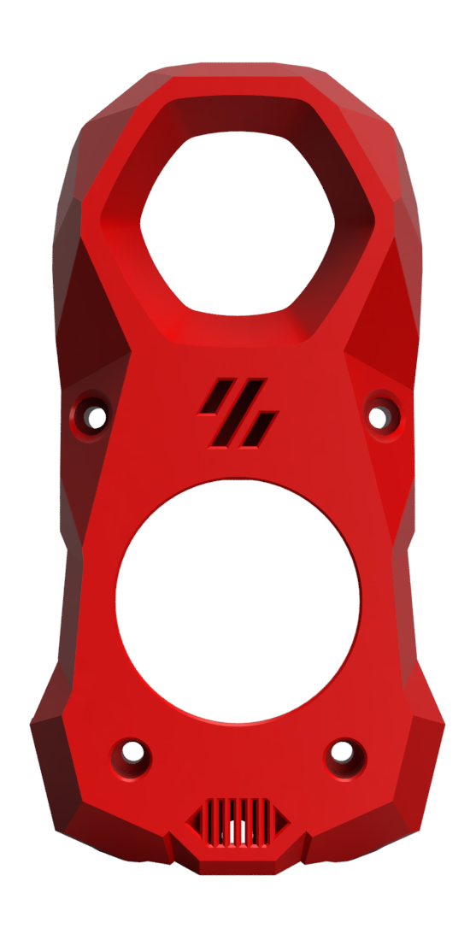
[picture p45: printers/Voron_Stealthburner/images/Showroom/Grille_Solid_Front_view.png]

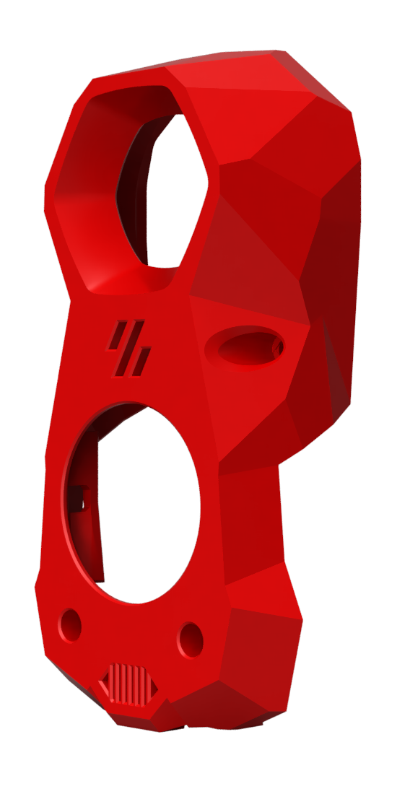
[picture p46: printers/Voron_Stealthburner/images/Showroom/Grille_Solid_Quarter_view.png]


### With color change
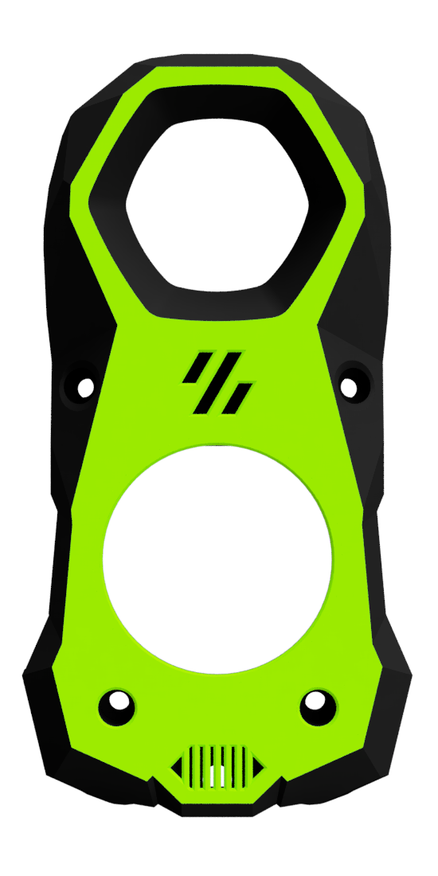
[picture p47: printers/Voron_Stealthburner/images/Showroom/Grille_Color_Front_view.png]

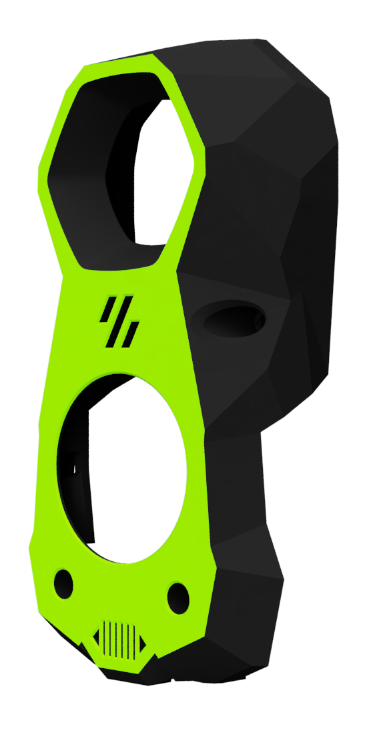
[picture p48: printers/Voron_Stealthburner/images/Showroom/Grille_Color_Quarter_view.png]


### With stroke
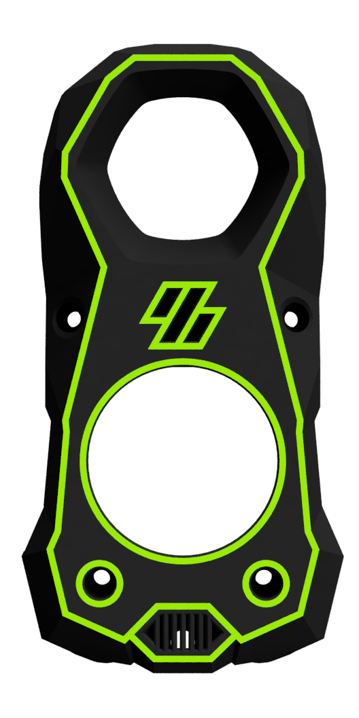
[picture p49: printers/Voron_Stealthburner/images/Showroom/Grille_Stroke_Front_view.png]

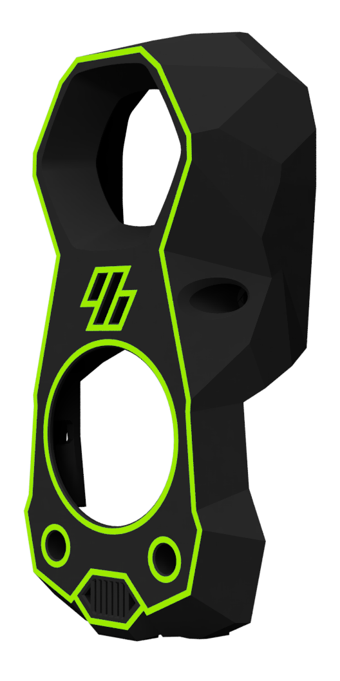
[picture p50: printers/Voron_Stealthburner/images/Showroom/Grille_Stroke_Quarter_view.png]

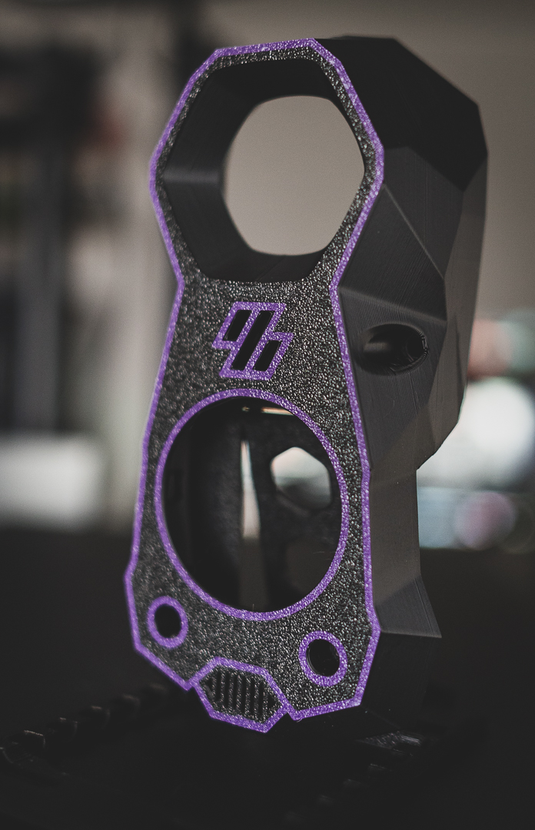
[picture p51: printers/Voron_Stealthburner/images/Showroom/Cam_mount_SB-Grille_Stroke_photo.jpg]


## HEX Edition
------
A version based on <a href="https://www.printables.com/model/225153-voron-stealthburner-face">3DP-MAMSIH</a>'s design with a hex pattern on the front face. Small air intake added on the face below the front to keep the front clean. 

### Renders
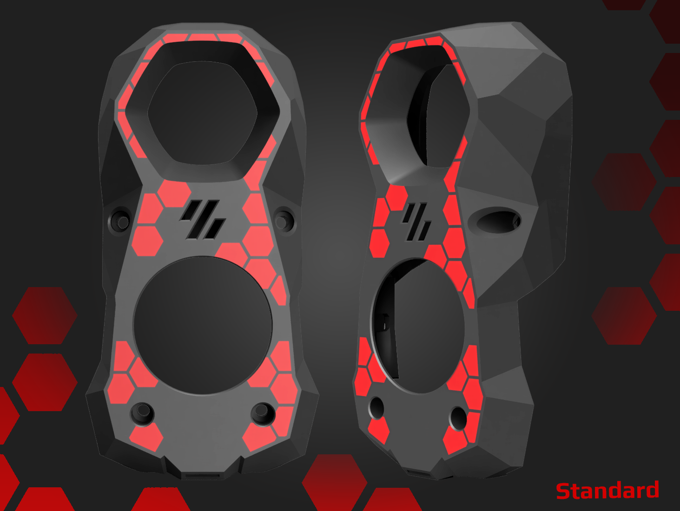
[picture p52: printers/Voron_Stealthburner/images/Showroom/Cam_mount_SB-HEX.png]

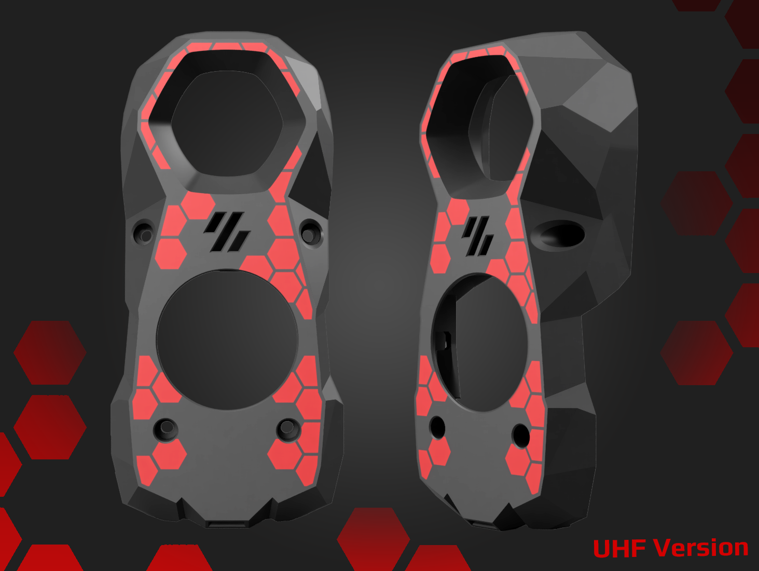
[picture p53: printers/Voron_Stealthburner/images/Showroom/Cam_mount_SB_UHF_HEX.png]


### Photos

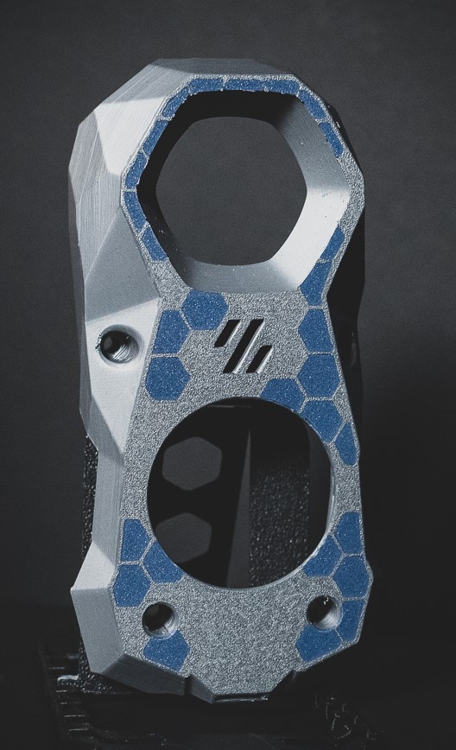
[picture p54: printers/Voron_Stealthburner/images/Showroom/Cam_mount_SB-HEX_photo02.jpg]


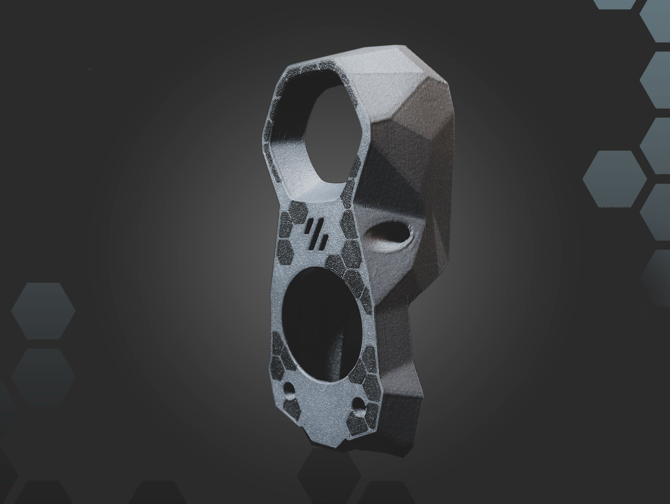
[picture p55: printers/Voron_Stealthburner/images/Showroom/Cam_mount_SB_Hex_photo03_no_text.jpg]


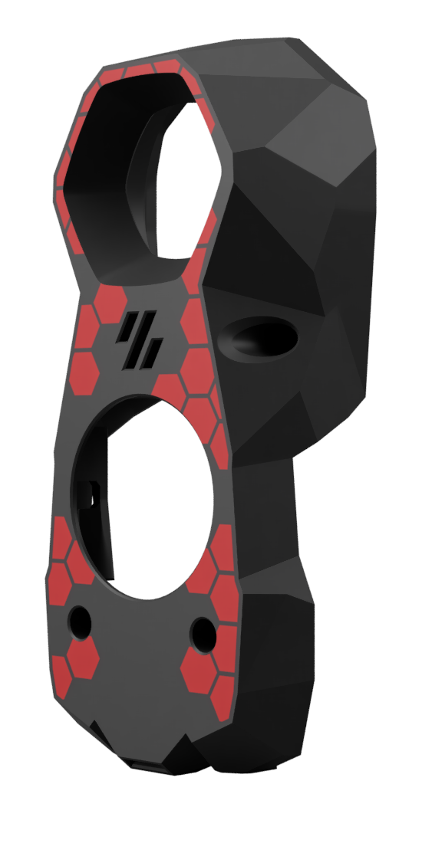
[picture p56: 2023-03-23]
printers/Voron_Stealthburner/images/Showroom/Cam_mount_SB_UHF-HEX_Quarter_view.png

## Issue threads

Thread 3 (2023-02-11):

USB cable from camera to Raspberry PI

z00mantwo, 2023-02-11:
Can I just run four 24awg Linneo 40 stand wires from the camera controller board in the tool head to a solder on USB connector at the PI? Or is a larger wire needed? Possibly 20awg?

Also what is the connector type at the camera board? Looks like a 5 conductor connector of some type.

thbl, 2023-03-05:
it a normal usb 2.0 cable, using a 5pin connecter with 1,0mm pitch

Closed 2023-03-05.

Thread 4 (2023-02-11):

3D model of IMX258 camera

arsi-apli, 2023-02-11:
I made a simple 3D model of the IMX258 camera. I also added a focus window, for a resolution of 800x600 and a focus length of 32mm from the back of the camera. I tried to measure it today and the sharpest image comes out at that 32mm.
https://cad.onshape.com/documents/fd0fddae3badd59be00c2c5a/w/82d33f3f9ffa0c6dbaafe43e/e/5e3cb29dfecb02d187eca4b2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

And I'm starting to work on my version for Hemera XS+ 3D printed Hermit CRAB + CPAP blower
https://cad.onshape.com/documents/c995be608a88407895310cc1/w/17480634f20bc058e5809fa7/e/f379a3a739f7b14b5432ae84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

btw, what is the best camera angle?

thbl, 2023-03-05:
*Focus distance from the back side of the camera to the object is set to 34.5mm

Closed 2023-03-05.

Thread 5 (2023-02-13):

Request: mounting for Bambu Lab X1

chaugan, 2023-02-13:
I hope someone is able to create a mounting for the Bambu Lab X1!

chuckkay, 2023-02-14:
Im hoping for a mount as well and hopefully someone figures a way to use the existing USB-C cable in the Bambu x1 Hotend housing (like with a splitter)

chaugan, 2023-03-05:
@thbl was the support for Bambu Lab dropped or added?

Closed 2023-03-05.

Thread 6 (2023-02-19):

Nozzle cam board and sb2040

33martin, 2023-02-19:
is it possible to use the nozzlecam board and the sb2240 can board together (is there enough space behind the fan)

thbl, 2023-03-05:
There should be enough space behind the stepper motor

33martin, 2023-03-06:
@whi-tw this is exactly what i mean.....

arekm, 2023-05-21:
Was considering this nozzle cam but looks like this issue is not solved (and even ignored). Please reopen.

Closed 2023-03-05.

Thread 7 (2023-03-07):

H.264 Encoding

whi-tw, 2023-03-07:
Hullo,

Is there anything in the works to either enable H.264 encoding on the existing encoder board (unsure if this is possible?) or to put out a board that does support H.264?

MJPG is great if you have a GPU / hardware MJPG encoding available, but 3D printer webcams are predominantly connected to arm(64) SBCs which have hardware H.264 encoding, but dealing with MJPG is painful.

Context: I've bought a 4K webcam, capable of 1080p60, but because of the heft of the MJPG stream, I'm barely able to stream the feed at ~20 fps consistently!

Thanks,

Tom

thbl, 2023-03-18:
@whi-tw well it depends on your hardware, if you use a PC instead of a pi to stream you probably will get better results.
But there is a h264 / webrtc for Rpi in the works, will be released when we are ready ! ;)

Closed 2023-03-18.

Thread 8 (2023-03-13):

Voron 2.4 - Are we to route the supplied USB cable through the gantry cable chain?

RudyAlbertoAcostaMarmalade, 2023-03-13:
Quick question - the supplied USB cable is quite 'chunky', is the expectation for Voron users to route the cable into and through the existing Voron gantry cable chains? If so, due to it's size I cannot help but think this would have detrimental impact on the movement of the chains, which may subsequently impact printing/quality. Can you please confirm if this is the case?

Or, are we meant to remove the a majority of the USB cable's outer sheath exposing the five inner cables and route those through the Voron Gantry cable chain, if so, are the inner wires of the supplied USB cable Heflon/Teflon based so that they can withstand the repeated movements?

Thanks in advance.

thbl, 2023-03-18:
most peopel now days use umbrella mod, that said we have used it without problems in cables chains.
We do not recommend to remove the outer shell of USB cable, as its protects cable aginst bend,heat, and EMI

RudyAlbertoAcostaMarmalade, 2023-03-19:
Good to know - Thanks for the response.

grzbiet, 2023-07-04:
> most peopel now days use umbrella mod
what's the umbrella mod, seems I can't google anything like that related to voron or even any 3d printer...

fryc88, 2023-07-12:
Probably they mean umbilical mod ;)

Closed 2023-03-18.

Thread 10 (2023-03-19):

camera after usb cable extension not working

frozenowni, 2023-03-19:
Hello,
I'm working on my voron 2.4 with stealthburner toolhead. Unfortunately i only ordered the usb cable in 1 m length, which is way too short for my 350³ build... (needs >= 2.5 m)
I provisionally installed the HD version of the nozzle cam using the original usb cable and was happy that it worked there.
After that i cut the usb cable and inserted 2 m of cable between the original plug and the camera side cable (soldered cables and checked continuity)
Unfortunately now the camera is not working anymore.

The situation is:
- camera shows up on lsusb
- camera does not show up in ls /dev/video*
- camera does not show up in dmesg | grep Webcam

I don't get, where the error might be. Thought this might be a problem others stumble accross so decided to report as an issue.

Thx in advance and BR

thbl, 2023-03-20:
the issue is no cable length as ours 3.5m works fine.
It's really hard to say what it is without the PCB in hand, but defiantly hardware related.

frozenowni, 2023-03-20:
Hi,
Thanks for the reply. I'm gonna order the appropriate length. However in the meantime I'd like to make one myself.
Is there a pinout for the adapter board?

Closed 2023-03-20.

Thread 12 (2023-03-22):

Simple LED mounting file?

SupItsSaige, 2023-03-22:
The cam mount file is provided as "3NC_mount_geometry_V2.step" to make it easier so we can make our custom camera mount attachments. Is there basic led mount file that could also be provided? Like maybe a segmented version of the attached image? I can try to trial and error my own led mounting model, but I thought it would be a huge time saver if there was an already made mode I could grab and go with. Thanks!

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

SupItsSaige, 2023-03-23:
@thbl I wasn't look for the model of the led itself, I was hoping there would be the simple mount modeled to hold the led. Similar to how "3NC_mount_geometry_V2.step" is provided as a basic mount for the camera.

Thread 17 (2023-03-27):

Stealthburner PCB Mount?

bradtn, 2023-03-27:
I know there's a ADXL mount but it's kind of a little ugly for my tastes. The back of my stepper also isn't available for the 3do pcb as I have a canbus board. I am wondering if someone more skilled than I could create a mount for the inside of the stealth burner where normally the pcb would be mounted as I won't be using said mount that would be the most ideal enclosed location?

thbl, 2023-03-27:
see https://github.com/3DO-EU/nozzle-camera/tree/main/printers/Voron_Stealthburner/Cam_mount_SB%20mod%20by%20Panzarkatten

thbl, 2023-03-27:
see https://github.com/3DO-EU/nozzle-camera/tree/main/printers/Voron_Stealthburner/Cam_mount_SB%20mod%20by%20Panzarkatten

testack18, 2023-08-18:
Why is this thread closed? That link does not really a mount. Its just some fancy face for the SB and a bit of cutout for the USB cable. There is no proper mount option for the PCB inside the toolhead like the topic opener asked.

Also the main body of the SB toolhead modification is not a well designed. I tried to push the fu...ng ribbon cable into it while trying to avoid putting it into the path of the airflow. Its hard to push the cable into the channels without damaging it. The whole design should re-think or have an official statement that it is not supported to put it and mount it within the toolhead.

Closed 2023-03-27.

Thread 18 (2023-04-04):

LED mounting

SupItsSaige, 2023-04-04:
So my first issues was closed without being addressed. Is there an simple mount stl file that could be provided for the LEDs? There is a simple mount provided for the cam itself (3NC_mount_geometry_V2.step). I was hoping it could save me and many others who need to customize things a lot of time.

Closed 2023-04-26.

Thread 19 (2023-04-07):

Connecting the LEDs

Siiggyy, 2023-04-07:
Could someone explain to me how i would need to connect the LEDs to some sort of power what would be the best option?

Mattang-Tim, 2023-04-20:
The LED configuration and setup can be found in the stealthburner repo.

Siiggyy, 2023-04-26:
Thanks for your answer but unfortunately this did not help me since i do not own a stealthburner. I found a workaround with a ocotoprint plugin but it's not optimal. Is there another option to get it running over a raspberry pi running octoprint?

Closed 2023-04-26.

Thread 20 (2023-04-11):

Stock self-tapping screws are too big for SB ADXL mount

truelecter, 2023-04-11:
So I've mounted PCB on the [PCB_mount_SB.stl](https://github.com/3DO-EU/nozzle-camera/blob/main/printers/Voron_Stealthburner/PCB_mount_SB.stl), but when testing that things are working I've found out that one of the screws actually squished one of the resistors, I assume and the camera, obviously, was not able to process images. It was correctly recognized as a "PC Camera", but no image was shown.

I've included the location of the element. Can you please tell me what this was so that I can replace it?
Also please, update the mount, so others will not have the same problem
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

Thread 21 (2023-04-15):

Camera goes offline when nozzle contacts brass cleaning brush.

junkTzu, 2023-04-15:
I'm having an issue where when my print head goes through the clean nozzle routine it causes the camera to go offline. If you watch the video you can see it go offline right as the nozzle comes in contact with the brass brush. I'm confident it's not a cabling issue since the camera will stay offline until I remove and reinsert the USB cable at my OrangePi. After I do that the camera works without issues for the duration of the print. I'm suspecting it's a grounding issue so I'm trying a few ideas out but I wanted to see if anyone else has also run into this issue.

junkTzu, 2023-04-16:
Upon closer investigation the issue was that the brass brush was coming into contact with the camera PCB causing a short. Modifying the nozzle cleaning parameters has resolved the issue.

Closed 2023-04-16.

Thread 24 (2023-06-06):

Duct utilizing Beacon?

hreality, 2023-06-06:
Could I persuade you to release an Eva3 duct modeled to utilize beacon and the camera also?

thbl, 2023-09-22:
we dont have plans for that sorry

Closed 2023-09-22.

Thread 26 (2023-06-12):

SB front for knomi screen and nozzle camera?

B1ack0u1, 2023-06-12:
afternoon all, just wondering if there is a StealthBurner front availible that includes the knomi screen and nozzle cam? cam board will be mounted on adlx

thanks :)
Stu

Closed 2023-09-22.

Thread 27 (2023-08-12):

Main Body Cutout STL Update

ADKMechETECH, 2023-08-12:
The model for the cutout main body to mount the PCB with a 2 piece tool board is still the Stealthburner Beta version. There were some changes made to the locating features in the release version that are not compatible.  See images below.  Can this part be updated to add the cutout to the relese version please?
CW2_main_body_3do_pcb_cutout.stl

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

Closed 2023-10-18.

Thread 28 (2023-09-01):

Useless fixed focal length

Kaelum, 2023-09-01:
Unless you are able to mount this at the EXACT distance away from the nozzle tip, good luck in using it.  The lens cannot be adjusted, so don't waste your time, or money, trying.

jonyo, 2023-09-17:
The docs mentioned it is fixed with glue and if you adjust it, they say to add glue replacement... I'm guessing you had trouble removing the existing glue? What kind of glue was it, just hot glue or what @Kaelum ?

Kaelum, 2023-09-17:
The glue appears to be some kind of CA glue, which you can break free, but you will seriously deform the plastic in doing so.  If there are any threads, the threads will be destroyed too, as I don't see any threads at all.  They made some seriously bad choices in creating this, and not providing an adjustment tool is just plain stupid on their part.  This product is not ready for sale.

Closed 2023-09-22.

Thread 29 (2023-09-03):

Ender 3 support and CAD model for camera sensor

daiceman825, 2023-09-03:
Is there any plan on making a mounting solution for the Ender line of printers from Creality?

Also, can the critical dimensions for the camera sensor be made available like the PCB CAD model?

trrotman, 2023-09-03:
I'm also looking for a mounting solution for an Ender 3 pro with this camera.

Closed 2023-09-22.

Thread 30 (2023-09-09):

USB-C Connector

wuast94, 2023-09-09:
would be nice to change the Connector on the board with something more reliable like a USB-C connector, i have my many trouble with this little 5 pin connector on the board

Closed 2023-09-22.

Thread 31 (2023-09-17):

Request: mount for Creality CR-6 SE / MAX

jonyo, 2023-09-17:
I've looked on printables and the other site, no one has made a mount for my printer yet Creality CR-6 MAX. The same design would work for CR-6 MAX or CR-6 SE since they share the same printer head design. The MAX may just need a longer cable but that is not a part of the mount.

Thanks!

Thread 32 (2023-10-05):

Please post valid pics and docs regarding FPC routing

testack18, 2023-10-05:
Am I the only one having a hard time figuring out how to route the FPC within SB main body?

What I want and checked:
I'm using the hartk 2 pieces PCB -> How to mount cam PCB?
Checking this issue which is already closed: [ #Stealthburner PCB Mount?](https://github.com/3DO-EU/nozzle-camera/issues/17)
On the recommended link there is no mount option. That link does not really a mount. Its just some fancy face for the SB and a bit of cutout for the USB cable. There is no proper mount option for the PCB inside the toolhead like the topic opener asked in issue #17 .
Also none of the STLs provided under [Cam_mount_SB mod by Panzarkatten](https://github.com/3DO-EU/nozzle-camera/tree/main/printers/Voron_Stealthburner/Cam_mount_SB%20mod%20by%20Panzarkatten) correlates to the [shown image](https://github.com/3DO-EU/nozzle-camera/blob/main/printers/Voron_Stealthburner/Cam_mount_SB%20mod%20by%20Panzarkatten/Images/Pcb_mount_in_SB.jpg).
Once you zoom in, the cam FPC cable is either just disappear somewhere in the body or is just folded back. It clearly just not moving downwards. Furthermore, none of the STL has that wide cutout shown in the image. You cannot see anything where that FPC goes as the picture taken on an angle where nothing can properly seen (marked with orange). Its impossible to track/learn how it supposed to be routed and the picture is... ehmm.. kinda questionable.
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

On the other hand, in the Voron_Stealtburner folder there is a picture referred as "[FPC_DONT_PULL.jpg](https://github.com/3DO-EU/nozzle-camera/blob/main/printers/Voron_Stealthburner/images/FPC_DONT_PULL.jpg)".
The marked with orange part is definietly much longer for the Magnum_plus_UHF than for the 'normal' cam_mount_SB. There is not enough room here to fold the ribbon cable as shown on that picture for the cam_mount_SB. If I would try to do it, it will definietly break the FPC.
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

The [image](https://github.com/3DO-EU/nozzle-camera/blob/main/printers/Voron_Stealthburner/images/FPC_INTERNAL.jpg) shows how to route the FPC within the SB is not clear.
The cable channel goes up from the hotend fan to the top part cooling fan is not deep enough to push the FPC within. How is the cable folded there to avoid blocking the air coming from the part fan? From this angled picture its impossible to see.

In general, some of the pictures not correlates to the provided STLs and some of them are either bad or just not clear.
Without clear documentation and pictures the risk to break that weak FPC is really high.
Please provide more pictures aligned with the uploaded STLs.
Please provide pictures created from diferent angle to be able to track how it is designed, how it is supposed to be.

Or just say its not supported to mount the PCB within the SB toolhead. But in this case, do not put a 25cm FPC on the cam, if we have to mount on the ADXL mount point.

panzarkatten, 2023-10-18:
Hi @testack18 and thanks for your feedback! I'll try to answer your questions below.

1. No there is no actual mount for the PCB inside the Stealthburner face since there just isn't that much room for a mount. I have tried to come up with good solution to no avail. Possibly without the 2-piece hartk board it would be doable but I have not explored that option. If you want to hold it in place maybe a small piece of VHB tape could work. For me the part cooling cable is enough to hold it in place.

2. The wide cutout you see in the [image](https://user-images.githubusercontent.com/37906467/273040938-603f7c5a-0ba8-4549-85a7-9103ae91b0e4.jpg) is just because I broke off the small piece that is there in the model to make room for the LED dupont connector.

3. It is possible to route the FPC as shown in the "do not pull" image on the non UHF version as well. But I would personally recommend to route the cable straight up and then do a 90 degree fold on the cable to avoid putting unnecessary strain on it where it attaches to the sensor.
<p align="center">
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</p>

4. Here you have some extra images showing how I routed the FPC cable. It's routed along the right side and then above the hotend fan continuing up the cable path in the slit added to the model and then folded two times before reaching the PCB.
<p align="center">
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
</p>

5. And for information, I have no affiliation with the company 3DO. I have just made and shared some SB face models with the camera mount etc.

testack18, 2023-10-26:
Thanks for taking the time and answering detailed all my problems.
In the meanwhile I found [this ](https://www.printables.com/de/model/565312-3do-nozzle-camera-pcb-mount-cover-with-thermistor-)for PSB mount. Not exactly within the main body, but its hidden, not outside the SB. Maybe its useful for others as well.

Closed 2023-10-18.

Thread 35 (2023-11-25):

Nozzle cam mount just a little low for Rapido

pfielding, 2023-11-25:
I've installed this camera with a Rapido hotend.  In general it works, but I'm finding that the bottom of the camera mount is just barely above the height of the nozzle tip.  Then end result is that if there are any issues, at all, with the print causing any sort of lift or raised filament at all, that the bottom of the toolhead (at the nozzle mount) can catch on the part.

Any chance of modding one of the front plates to have the nozzle cam mount just a liiiiiitle bit higher up?

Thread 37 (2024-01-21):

Where mount board on SB with BTT 2209?

rmilyard, 2024-01-21:
The board takes up to much space so trying to figure out how to mount the board on this setup.  Ideas?

oz1sms, 2024-02-07:
Try ADXL345 mount

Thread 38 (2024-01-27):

Camera randomly stops working

imightbelosthere, 2024-01-27:
So... Camera works great... when it works of course!

I have it installed on a Stealthburner Toolhead with an SB2209 board and due to the lack of space or better spot to place the camera board, I placed it next to the umbilical cord and secured it with a couple zip ties.

My problem is... camera's working fine and all of a sudden, at random interval it stops working. I have to go, unplug the cable (literally) from the board and once plugged back in it works fine again but it can fail again (randomly).

I've checked with the lsusb after the failure and I can see the device in the USB list.

I have two other cameras and they don't stop transmitting at any point so I'm a bit lost... what could be the issue here? Where can I start the troubleshooting?

Thanks

testack18, 2024-02-18:
Having the same issue. In the logs nothing much just device not found.

imightbelosthere, 2024-02-18:
> Having the same issue. In the logs nothing much just device not found.

I found that restarting the Crowdsnest service made the camera get back working again. But the way it fails makes me think it's something hardware related but... Need more testing.

testack18, 2024-02-18:
In my case, this does not helps at all. For me, only full reboot helps.
This is the log during crowsnest restart:
```
[02/18/24 21:12:59] crowsnest: ERROR: No usable Devices Found. Stopping crowsnest.
[02/18/24 21:13:04] crowsnest: crowsnest - A webcam Service for multiple Cams and Stream Services.
[02/18/24 21:13:04] crowsnest: Version: v4.1.3-1-gc0c9c41
[02/18/24 21:13:04] crowsnest: Prepare Startup ...
[02/18/24 21:13:04] crowsnest: INFO: Host information:
[02/18/24 21:13:04] crowsnest: Host Info: Distribution: Raspbian GNU/Linux 11 (bullseye)
[02/18/24 21:13:04] crowsnest: Host Info: Kernel: Linux 6.1.21-v8+ aarch64
[02/18/24 21:13:04] crowsnest: Host Info: Model:  Raspberry Pi 4 Model B Rev 1.5
[02/18/24 21:13:04] crowsnest: Host Info: Available CPU Cores: 4
[02/18/24 21:13:04] crowsnest: Host Info: Available Memory: 3705536 kB
[02/18/24 21:13:04] crowsnest: Host Info: Diskspace (avail. / total): 47G / 59G
[02/18/24 21:13:04] crowsnest: INFO: Checking Dependencies
[02/18/24 21:13:04] crowsnest: Dependency: 'crudini' found in /usr/bin/crudini.
[02/18/24 21:13:05] crowsnest: Dependency: 'find' found in /usr/bin/find.
[02/18/24 21:13:05] crowsnest: Dependency: 'xargs' found in /usr/bin/xargs.
[02/18/24 21:13:05] crowsnest: Dependency: 'ustreamer' found in bin/ustreamer/ustreamer.
[02/18/24 21:13:05] crowsnest: Dependency: 'camera-streamer' found in bin/camera-streamer/camera-streamer.
[02/18/24 21:13:05] crowsnest: Version Control: ustreamer is up to date. (v5.41)
[02/18/24 21:13:05] crowsnest: Version Control: camera-streamer is up to date. ((ef8f6a4))
[02/18/24 21:13:05] crowsnest: INFO: Print Configfile: '/home/pi/printer_data/config/crowsnest.conf'
[02/18/24 21:13:05] crowsnest:		[crowsnest]
[02/18/24 21:13:05] crowsnest:		log_path: /home/pi/printer_data/logs/crowsnest.log
[02/18/24 21:13:05] crowsnest:		log_level: debug
[02/18/24 21:13:05] crowsnest:		delete_log: false
[02/18/24 21:13:05] crowsnest:		no_proxy: false
[02/18/24 21:13:05] crowsnest:
[02/18/24 21:13:05] crowsnest:		[cam NozzleCam]
[02/18/24 21:13:05] crowsnest:		mode: camera-streamer
[02/18/24 21:13:05] crowsnest:		enable_rtsp: true
[02/18/24 21:13:05] crowsnest:		port: 8080
[02/18/24 21:13:05] crowsnest:		device: /dev/v4l/by-id/usb-XCG-230315-J_3DO_NOZZLE_CAMERA_4K_01.00.00-video-index0
[02/18/24 21:13:05] crowsnest:		resolution: 1920x1080
[02/18/24 21:13:05] crowsnest:		max_fps: 30
[02/18/24 21:13:05] crowsnest:
[02/18/24 21:13:05] crowsnest: INFO: Detect available Devices
[02/18/24 21:13:05] crowsnest: ERROR: No usable Devices Found. Stopping crowsnest.

```

And this log repeats every few seconds after the video went black screen:

```
[02/17/24 16:14:14] crowsnest: DEBUG: camera-streamer [cam NozzleCam]: rpivid (platform:rpivid):
[02/17/24 16:14:14] crowsnest: DEBUG: camera-streamer [cam NozzleCam]: /dev/video19
[02/17/24 16:14:14] crowsnest: DEBUG: camera-streamer [cam NozzleCam]: /dev/media2
[02/17/24 16:14:14] crowsnest: DEBUG: camera-streamer [cam NozzleCam]:
[02/17/24 16:14:14] crowsnest: DEBUG: camera-streamer [cam NozzleCam]: cmd/camera-streamer/main.c: ?: Automatically reconnecting in 1 seconds...
[02/17/24 16:14:15] crowsnest: DEBUG: camera-streamer [cam NozzleCam]: device/v4l2/device.c: CAMERA: Can't open device: /dev/v4l/by-id/usb-XCG-230315-J_3DO_NOZZLE_CAMERA_4K_01.00.00-video-index0
[02/17/24 16:14:15] crowsnest: DEBUG: camera-streamer [cam NozzleCam]: device/device.c: CAMERA: Can't open device: /dev/v4l/by-id/usb-XCG-230315-J_3DO_NOZZLE_CAMERA_4K_01.00.00-video-index0
[02/17/24 16:14:15] crowsnest: DEBUG: camera-streamer [cam NozzleCam]: device/camera/camera_input.c: CAMERA: Listing available v4l2 devices:
[02/17/24 16:14:15] crowsnest: DEBUG: camera-streamer [cam NozzleCam]: Cannot open device /dev/video0, exiting.
[02/17/24 16:14:15] crowsnest: DEBUG: camera-streamer [cam NozzleCam]: bcm2835-codec-decode (platform:bcm2835-codec):
[02/17/24 16:14:15] crowsnest: DEBUG: camera-streamer [cam NozzleCam]: /dev/video10
[02/17/24 16:14:15] crowsnest: DEBUG: camera-streamer [cam NozzleCam]: /dev/video11
[02/17/24 16:14:15] crowsnest: DEBUG: camera-streamer [cam NozzleCam]: /dev/video12
[02/17/24 16:14:15] crowsnest: DEBUG: camera-streamer [cam NozzleCam]: /dev/video18
[02/17/24 16:14:15] crowsnest: DEBUG: camera-streamer [cam NozzleCam]: /dev/video31
[02/17/24 16:14:15] crowsnest: DEBUG: camera-streamer [cam NozzleCam]: /dev/media3
[02/17/24 16:14:15] crowsnest: DEBUG: camera-streamer [cam NozzleCam]:
[02/17/24 16:14:15] crowsnest: DEBUG: camera-streamer [cam NozzleCam]: bcm2835-isp (platform:bcm2835-isp):
[02/17/24 16:14:15] crowsnest: DEBUG: camera-streamer [cam NozzleCam]: /dev/video13
[02/17/24 16:14:15] crowsnest: DEBUG: camera-streamer [cam NozzleCam]: /dev/video14
[02/17/24 16:14:15] crowsnest: DEBUG: camera-streamer [cam NozzleCam]: /dev/video15
[02/17/24 16:14:15] crowsnest: DEBUG: camera-streamer [cam NozzleCam]: /dev/video16
[02/17/24 16:14:15] crowsnest: DEBUG: camera-streamer [cam NozzleCam]: /dev/video20
[02/17/24 16:14:15] crowsnest: DEBUG: camera-streamer [cam NozzleCam]: /dev/video21
[02/17/24 16:14:15] crowsnest: DEBUG: camera-streamer [cam NozzleCam]: /dev/video22
[02/17/24 16:14:15] crowsnest: DEBUG: camera-streamer [cam NozzleCam]: /dev/video23
[02/17/24 16:14:15] crowsnest: DEBUG: camera-streamer [cam NozzleCam]: /dev/media0
[02/17/24 16:14:15] crowsnest: DEBUG: camera-streamer [cam NozzleCam]: /dev/media1
[02/17/24 16:14:15] crowsnest: DEBUG: camera-streamer [cam NozzleCam]:
[02/17/24 16:14:15] crowsnest: DEBUG: camera-streamer [cam NozzleCam]: rpivid (platform:rpivid):
[02/17/24 16:14:15] crowsnest: DEBUG: camera-streamer [cam NozzleCam]: /dev/video19
[02/17/24 16:14:15] crowsnest: DEBUG: camera-streamer [cam NozzleCam]: /dev/media2

```

```
pi@fluiddpivoron:~ $ libcamera-hello --list-cameras
No cameras available!

```

testack18, 2024-02-18:
not sure if this helps in any, but dmesg shows this:
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
testack18, 2024-03-29:
Well, this was my very first voron/klipper installed back in the time. I was still using it since a while. It was a 32 bit image of fluiddpi raspbian image.
Now for some reason, I have completly reflashed using 64 bit raspberry lite image and KIAUH installation of klipper. Since the  the issue seems gone. I only have a few tenth of hours of printing so maybe too early to state anything, but so far, so good. I haven't experie ced this problem since the reinstallation. But still testing/validating. Will see...

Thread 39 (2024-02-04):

FPC replacement possible?

lthown, 2024-02-04:
If the flat cable connected to the camera is damaged (too many folds, etc...) is there a way to replace the flat cable? Is the camera just e-waste now and the entire module needs to be replaced?

ReubenBTalbott, 2024-03-04:
Same question here, managed to rip mine on install 😢

Jdiaz031, 2024-03-05:
same question here as well, I've tried to look for a replacement but they've been out of stock

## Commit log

2023-01-15 first files
    [Eva_2.4.3mf]
2023-01-15 Adding files for Voron
    Adding files for Voron 2.4 mount and a general geometry for the camera holder
    [PCB_mount_SB.step, PCB_mount_SB.stl, PCB_mount_SB_extended.step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]
2023-01-15 Adding cam mount SB
2023-01-15 Edits to stl files, updating PCB mount step
    [PCB_mount_SB.step, PCB_mount_SB.stl, PCB_mount_SB_extended.stl]
2023-01-17 moved file
    [cam_mount_geometry_V2.step]
2023-01-19 Adding pcb taping jig, for internal mounting of pcb. Untested!
    [pcb taping jig.stl]
2023-01-19 Directory and naming fix
    [lgx-lite_pcb_taping_jig.stl]
2023-01-23 Added V-Edition SB mount
    [Cam_mount_SB-V.stl, Cam_mount_SB-V_stroke.stl]
2023-01-23 Added Grille Edition SB mount
    [Cam_mount_SB-Grille.stl]
2023-01-23 Added Readme.md and mount view image
2023-01-26 Added HEX version for regular SB
    [Cam_mount_SB_HEX.stl]
2023-01-26 Fixed orientation on Cam_mount_SB_HEX.stl
    [Cam_mount_SB_HEX.stl]
2023-01-27 Added HEX UHF version and fixed image links in readme.md
    [Cam_mount_SB-UHF_HEX.stl]
2023-03-04 Create Y end stop extended 15mm.3mf
    [Y end stop extended 15mm.3mf]
2023-03-23 Updated readme and added pcb mount option
    [CW2 main body 3DO mod.step, CW2_main_body_3do_pcb_cutout.stl, hex_pattern.dxf]
2023-03-30 VzBot update
    [CPAP_upper_duct.3mf, Cam duct + spacers.step, Cam_Goliath_duct.3mf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]
2023-03-30 added prusa
    [3DO Nozzle Cam Fan Mount for Prusa Mini - 22 deg right and 16.5 deg down V7.3.3mf, Nozzle Cam 3DO Komplett V11 PRINT.3mf, Nozzle Cam 3DO PCB Case V9.3mf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]
2023-04-23 added additional Prusa I3 MK3 files
    [Nozzle Cam 3DO PCB Case V9.stl, Nozzle Cam 3DO PCB Top V9.3mf, Nozzle Cam 3DO PCB Top V9.stl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]
2023-10-17 Updated for July 11 update of cw2
    [CW2 main body 3DO mod_updated.step, CW2_main_body_3do_pcb_cutout_updated.stl]
2023-10-18 Reorganization of Voron Stealthburner folder
    [CW2 main body 3DO mod.step, CW2 main body 3DO mod_updated.step, CW2_main_body_3do_pcb_cutout.stl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]
